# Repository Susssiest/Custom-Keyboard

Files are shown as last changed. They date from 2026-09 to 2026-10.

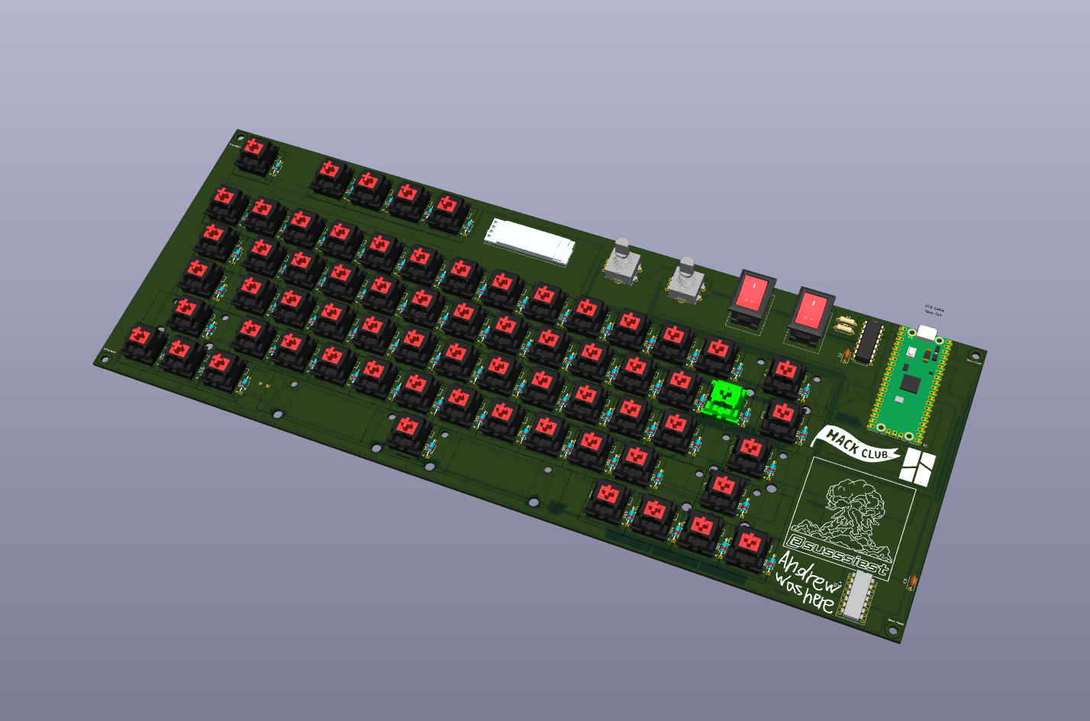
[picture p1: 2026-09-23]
Renders/PCB Render.png

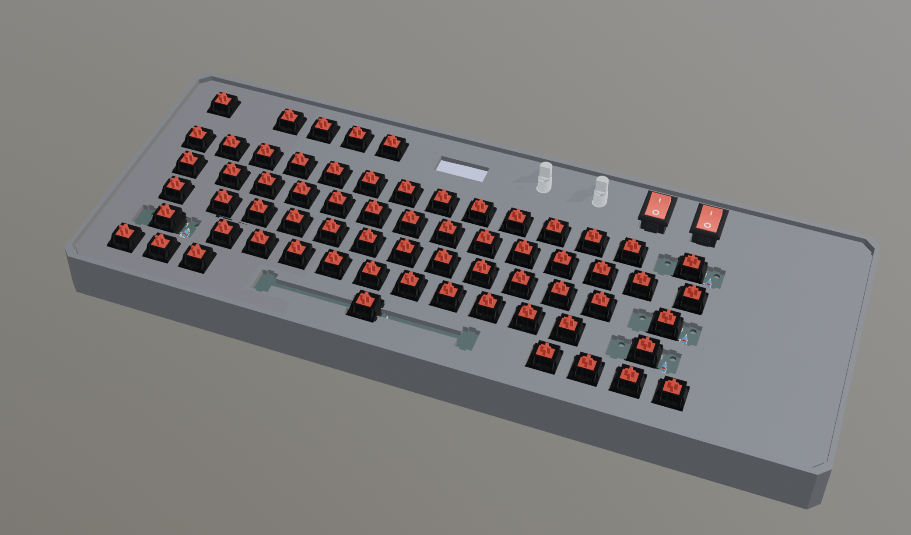
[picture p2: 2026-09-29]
Renders/Full Render.png

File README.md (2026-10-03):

# FORGE CORE

Screenshot 2026-09-23 at 10 50 05 AM
Full Render

## Summary

This is a custom 60% keyboard equipped with per key rgb leds, rotary encoders, rocker switches, and an oled screen. My orginal idea was to just have leds, rotary encoders, and spst switches, but I quickly realized that I needed to add many additional components to get it to work like I intended. The finished keyboard will have many custom features:

- Leds will uniformly glow, and when is a key ismpressed the led under it will flash brighter than all the other leds for a few seconds before fading.
- Rotary encoders will control screen brightness and window switching.
- Spsts will turn leds on and off, and full keyboard on and off.
- I may change function keys to isntead of working like default function keys, open apps, like kicad or fusion.
- Will have Kaihl hot swap sockets.
- OLED will display simple live keylogger.

# Keyboard Overview

## Keyboard Layout

The keyboard's top layer, (R0), is a little different than a normal 60% keyboard. It's main difference is instead of having a full function key layout, the row starts with escape key, and ends with f4, and then has the screen, rotary encoders, and spsts. I will solder on the hot swap sockets to the pcb, and use cherry mx key switches. The matrix will have diodes to right of each key, for each key. 

Screenshot 2026-09-19 at 5 26 41 PM

## Controller and GPIO

I'm planning on using a rp2040 pi pico as the controller, and having an extra gpio extender for the 4 extra pins that don't fit on the pico. The pico will be connected to the full matrix, and link to the led data and rotary encoder a and b signals. The gpio extender will have the two rotary encoder buttons connected to it, snd the two spsts. The PCF8574AP will have a 0.1uf capacitor next to it to protect the 3v3 pin.

Screenshot 2026-09-19 at 5 28 19 PM

## LEDs

LEDs will glow normally and then individually flash when key is pressed, I'm going to limit brightness in firmware as a safeguard. I will have a level shifter for the rgb data to convert the 3.3v data signal to 5v so the leds dont flicker or potentially not recieve commands. I will have a 1000uf capacitor on 5V roght before it reaches the first led. The level shifter will have a 330r resistor before the first led as well. The level shifter will have a 0.1 uf capacitor before 5V to protect the vcc pin.

Screenshot 2026-09-22 at 10 20 40 AM

## Rotary Encoders

I'm planning on one the rotary encoders for controlling volume, and another for controlling windows, I'm planning on configuring it to open the CMD+TAB menu and scroll to select and open windows, and then once the rotary encoder has stopped turnign for say, 1 second, the window will open snd the menu will close.

Screenshot 2026-09-22 at 10 21 06 AM

## SPST Switches

Already mentioned above, one of the spst switches will toggle the LEDs on and off, the other spst will just turn the keyboard on and off.

Screenshot 2026-09-22 at 10 21 21 AM

## OLED

The oled will show a live display of what keys are being pressed, but I may also just put a simple animation on it or logo. There are two 4.7k resistors to protect sda and scl from 3v3.

Screenshot 2026-09-22 at 10 21 35 AM

# Cad Assembly

https://github.com/user-attachments/assets/99ca1ac0-4308-4080-8bde-6a10d6c55312

# Prices

## Keyboard Parts BOM

| Item | Part Number | Description | Quantity | Notes | Price |
|---:|---|---|---:|---|---:|
| 1 | SC0915 | Raspberry Pi Pico | 1 | Microcontroller | $2.27 |
| 2 | MCP23017 | GPIO Extender | 1 | Need one. | $3.23 |
| 3 | KY040 | Rotary Encoder | 2 | — | $2.19 |
| 4 | SSD1306 | 0.91 in Screen | 1 | — | $1.09 |
| 5 | SK6812MINI-E | SK6812 MINI-E Reverse Mount | 66 | Specifically need reverse mount. | $6.04 |
| 6 | CPG151101S11 | Kailh Hot-Swap Sockets | 66 | Type 1, 70 count. | $8.19 |
| 7 | 1N4148 | Diodes | 66 | — | $2.11 |
| 8 | N/A | Ceramic Capacitors | 2 (0.1 µF) | — | $2.48 |
| 9 | N/A | Stabilizers | 6 | Need 2u and 7u. | $6.30 |
| 10 | MX1A | Cherry MX Switches | ~65 | Key switches; brown. | $19.10 |
| 11 | N/A | Shine-Through Keycaps | ~65 | — | $11.18 |
| 12 | KCD1-101 | Rocker Switch | 2 | Have already. | N/A |
| 13 | N/A | Resistors | 3 (330 Ω and 470 kΩ) | Have already. | N/A |
| 14 | Level Shifter | SN74AHCT125N | 1 | Have already. | N/A |
| 15 | N/A | Metal Film Capacitor | 1 (1000 µF) | — | N/A |

**Listed Total:** $64.

## Fabrication Stats

Screenshot 2026-09-23 at 11 26 51 AM

- **Total Price: $26.50**
- **Shipping Estimate: $18.20**

## Download blender files here -> https://drive.google.com/file/d/1HHVWuKGK5Ybn4Eovk-v0dPoQDrp0pe_T/view?usp=sharing

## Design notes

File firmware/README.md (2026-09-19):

# Keyboard (66) QMK Firmware

66-key ANSI 60% + F-row on a Raspberry Pi Pico.

## Files

```
keyboards/hackpad66/
  keyboard.json                 matrix, pins, encoders, RGB layout, LAYOUT_66
  config.h                      I2C0 on GP0/GP1, OLED, RGB brightness cap
  mcuconf.h                     enables the RP2040 I2C0 peripheral
  halconf.h                     enables ChibiOS I2C
  keymaps/default/
    keymap.c                    keymap, Cmd-Tab encoder, OLED, expander
    rules.mk                    pulls in the standalone I2C master driver
```

## Build

```bash
# once
python3 -m pip install --user qmk
qmk setup                       # clones qmk_firmware and installs the ARM toolchain

# copy this board in
cp -r keyboards/hackpad66 ~/qmk_firmware/keyboards/

# compile
qmk compile -kb hackpad66 -km default
```

Flashing: hold BOOTSEL while plugging in the Pico the first time, then drag the
`.uf2` onto the `RPI-RP2` volume. After that, **Fn+Esc** is `QK_BOOT` and puts
the board back into bootloader mode without touching the Pico — which matters,
because RUN is not broken out to a button.

## Pin map

| Function | Pins |
| --- | --- |
| Matrix columns C0–C12 | GP2–GP14 |
| Matrix rows R0–R5 | GP16–GP21 |
| RGB data (66 WS2812) | GP15 → SN74AHCT125N → 330 Ω |
| I2C SDA / SCL | GP0 / GP1 (I2C0) |
| Encoder 1 A / B | GP22 / GP26 |
| Encoder 2 A / B | GP27 / GP28 |

I2C bus: SSD1306 OLED at 0x3C, PCF8574A expander at 0x38 (no collision).

Expander pins: P0 = encoder 1 button, P1 = encoder 2 button,
P2 = left rocker (RGB), P3 = right rocker (screen).

Diode direction is COL2ROW — 1N4148 cathodes on the rows.

## The three relocated switches

To free one GPIO, three switches are wired into matrix row 5 despite sitting
physically elsewhere on the board:

| Switch | Legend | Physical row | Matrix position |
| --- | --- | --- | --- |
| SW7 | `1` | number row | R5, C2 |
| SW21 | `Q` | QWERTY row | R5, C3 |
| SW60 | Left Opt | bottom row | R5, C4 |

`LAYOUT_66` is written in physical reading order, so the keymap hides this.
It is recorded here and at the top of `keymap.c` because nothing in the
schematic or the code hints at it otherwise.

## Behaviour

**Encoder 1 — volume.** `KC_VOLD` / `KC_VOLU`, shaft press is `KC_MUTE`. This
is a host HID consumer-control command, so it adjusts the computer's system
volume and the OS decides which output device that lands on.

**Encoder 2 — app switcher.** Turning presses and holds Cmd, then taps Tab per
detent (Shift+Tab counter-clockwise). Cmd is released 1000 ms after you stop
turning, which commits the switch. Spinning faster than 70 ms per detent sends
2 taps per detent. Shaft press releases Cmd and fires `KC_MCTL` for Mission
Control. Note Cmd+Tab switches *apps*, not individual windows.

Tunables at the top of the Cmd-Tab section: `CMDTAB_COMMIT_MS`,
`CMDTAB_FAST_MS`, `CMDTAB_FAST_STEP`.

**Screen.** Shows currently held keys as `CMD+SHFT+4`. Modifier order is fixed
at Ctrl, Opt, Cmd, Shift, then regular keys. The display is 21 characters wide,
so long combos fall back from `CTRL+OPT+CMD+SHFT` to `C+O+M+S`, and wrap to a
second line only if still too long. Idle shows the board name and active layer.

**Rockers.** Left toggles RGB, right toggles the screen. Both are latching, so
their position is read at boot and applied immediately rather than waited on.

**RGB.** The board runs a moving rainbow across the keys (`cycle_left_right`)
whenever it is powered and the left rocker is on. Fn+F2 cycles to other
animations, Fn+F3/F4 adjust brightness, Fn+F1 toggles the LEDs. On the Fn layer
encoder 1 is brightness and encoder 2 steps through animations.

**RGB current safety.** 66 WS2812s at full white would draw roughly 3.9 A, but
they are fed from Pico VBUS through its polyfuse on a 500 mA port. Brightness
is capped at 110 in both `config.h` and `keyboard.json`. Do not raise it
without external 5 V power, and avoid full-white effects. The LEDs also boot
dark and fade in over ~1 s so they are not drawing current during USB
enumeration while the 1000 µF cap is still charging.

## Things to verify on first flash

These are the parts I could not test without your hardware:

1. **LED chain order.** `keyboard.json` assumes LED *n* in the chain
   corresponds to SW *n*. If your PCB routes the data line in a different
   order, per-key effects will look scrambled — fix the `rgb_matrix.layout`
   array, not the keymap.
2. **Encoder direction.** If an encoder turns the wrong way, swap `pin_a` and
   `pin_b` for it in `keyboard.json`.
3. **Encoder resolution.** Set to 4. If one detent produces two steps, change
   it to 2; if it takes two detents to move once, try 8.
4. **Expander address.** 0x38 assumes the PCF8574**A** variant with A0–A2 tied
   low. The non-A PCF8574 is 0x20 instead.
5. **Rocker polarity.** If a rocker is inverted, flip the `&` tests in
   `exp_task()` and `exp_apply_rockers()`.

## Not compiled

I do not have an ARM toolchain in this sandbox, so this has **not** been
through a compiler. The layout data is machine-verified — 66 keys, 66 LEDs,
66 macro arguments, no duplicate matrix positions — but expect to fix a
warning or two on the first build. The most likely spots are the I2C defines
in `config.h`/`mcuconf.h`, which vary between QMK versions, and the `RM_*`
RGB keycode names, which replaced the older `RGB_*` names in 2025.

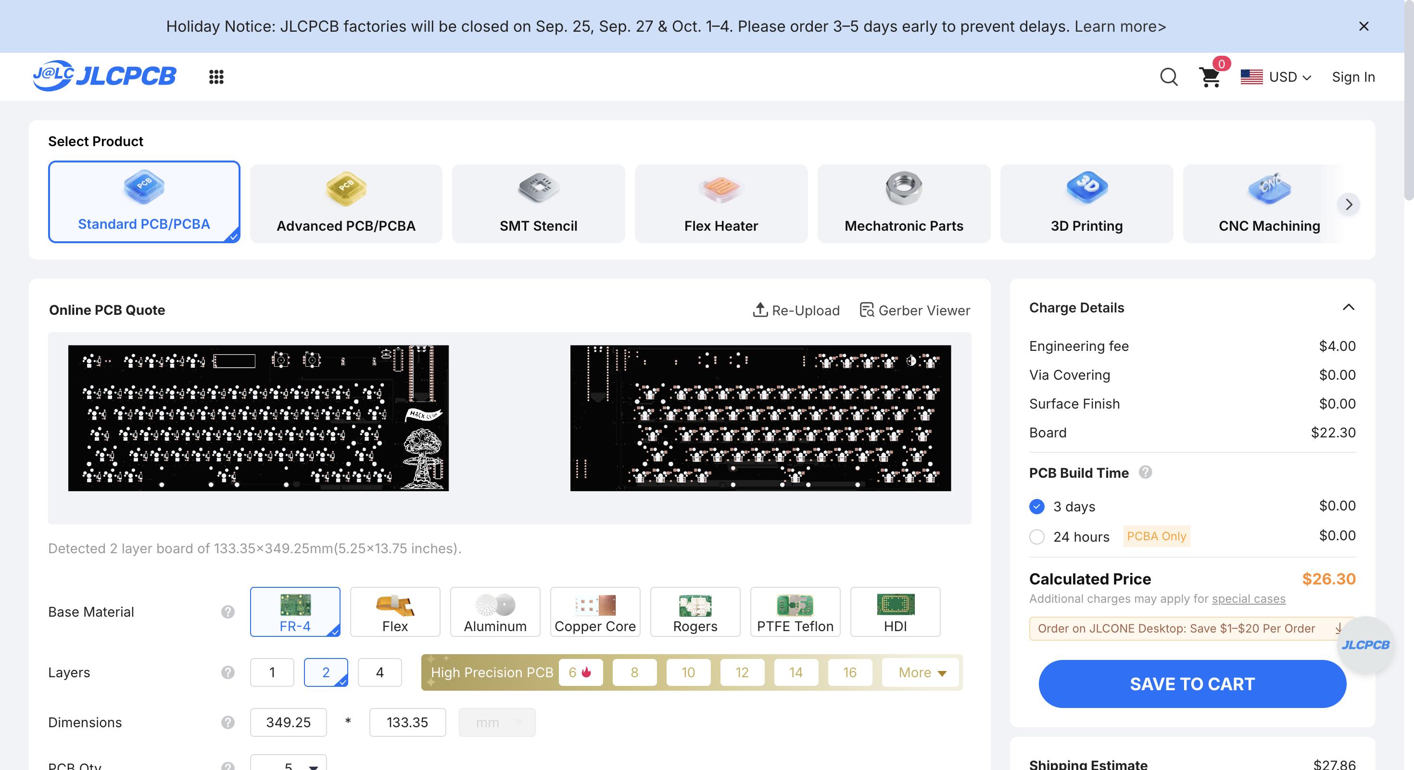
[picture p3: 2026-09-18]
Renders/JLCPCB Overview.png

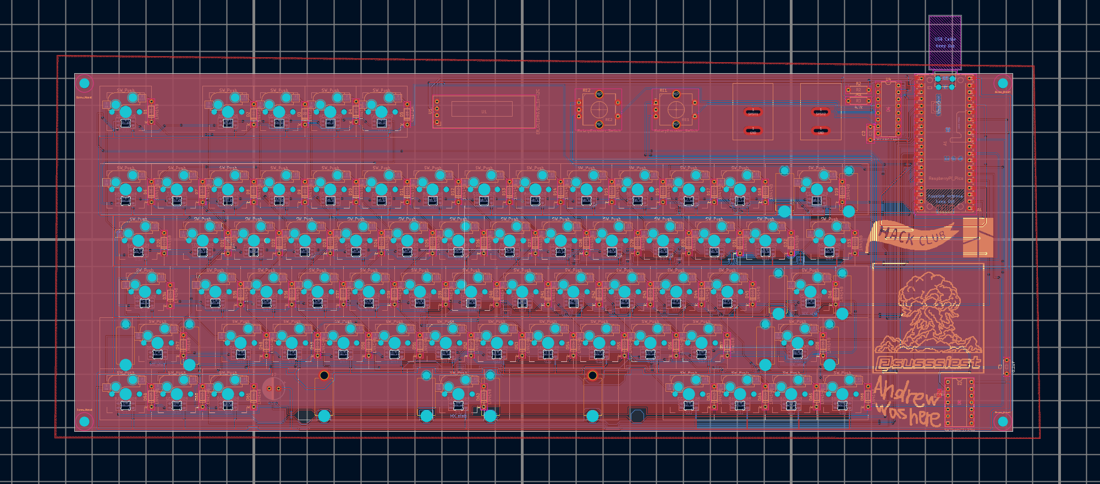
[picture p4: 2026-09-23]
Renders/PCB_Front.png

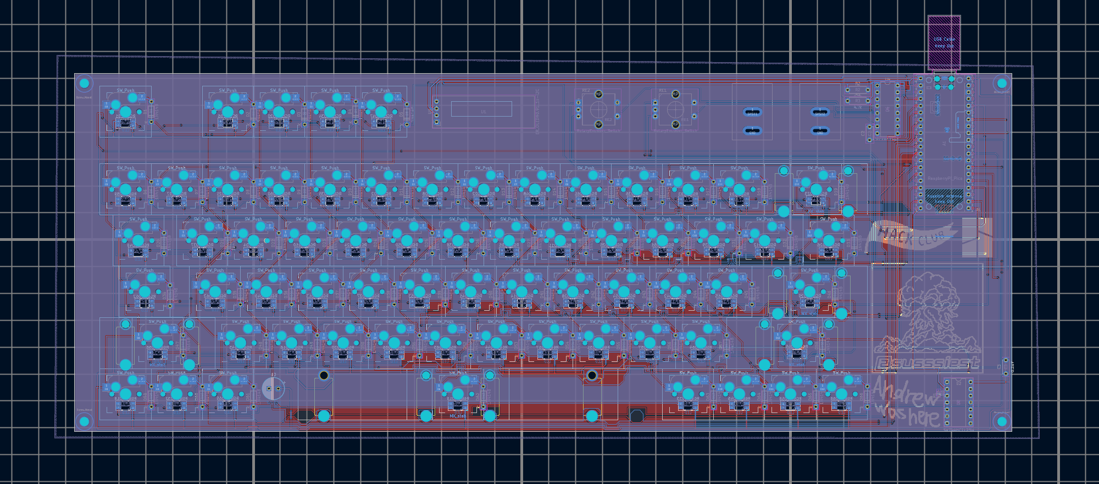
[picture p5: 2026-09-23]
Renders/PCB_Back.png

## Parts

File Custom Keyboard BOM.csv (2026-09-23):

Item | Part Number | Description | Quantity (PART) | Notes | Links | Prices | PCB Manufacturing | Totals | Shipping Estimate
1 | SC0915 | Rasberry Pi Pico | 1 | Micro controller | https://www.aliexpress.us/item/3256805430865417.html?curPageLogUid=Mookv4cZU7gI | $2.27 | $26.50 | Parts -64.19 | ~ $30
2 | MCP23017 | GPIO Extender | 1 | Need one. | https://www.aliexpress.us/item/3256806804890160.html?curPageLogUid=DZaA1o03SMNm | $3.23 |  | PCB - $26.50
3 | KY040 | Rotary Encoder | 2 |  | https://www.aliexpress.us/item/3256807457768762.html?curPageLogUid=t58zUy8mymUw | $2.19 |  | All - $80.69
4 | SSD1306 | 0.91 in Screen | 1 |  | https://www.aliexpress.us/item/2251832650376908.html?gatewayAdapt=glo2usa4itemAdapt | $1.09
5 | SK6812MINI-E | SK6812 MINI-E Reverse Mount | 66 | Specifically need reverse mount. | https://www.aliexpress.us/item/3256805007401420.html?curPageLogUid=upbCtOLX31bt | $6.04
6 | CPG151101S11 | Kaihl Hot Swap Sockets | 66 | Type 1, 70 count. | https://www.aliexpress.us/item/3256811824772840.html?curPageLogUid=uZFKQI2YgP81 | $8.19
7 | 1N4148 | Diodes | 66 |  | https://www.aliexpress.us/item/3256802064723285.html?curPageLogUid=Gxkmaeu7bYkX | $2.11
8 | N/A | Ceramic Capacitors | 2 (0.1uf) |  | https://www.aliexpress.us/item/3256801723894568.html?curPageLogUid=9Tlkmp6Rhsoe | $2.48
9 | N/A | Stabilizers | 6 | Need 2u, 7u. | https://www.aliexpress.us/item/3256806342416791.html?curPageLogUid=XBrMT8oQuSrr | $6.30
10 | MX1A | Cherry MX Switch | ~65 | Key switches. Brown. | https://www.aliexpress.us/item/3256802192387196.html?gatewayAdapt=glo2usa4itemAdapt | $19.10
11 | N/A | Shine through keycaps | ~65 |  | https://www.aliexpress.us/item/3256810117464722.html | $11.18
12 | KCD1-101 | Rocker Switch | 2 | Have already | N/A | N/A
13 | N/A | Resistors | 3 (330r and 470k) | Have already | N/A | N/A
14 | Level Shifter | SN74AHCT125N | 1 | Have already. | N/A | N/A
15 | N/A | Metal Film Capcacitor | 1 (1000 uf) |  | N/A | N/A

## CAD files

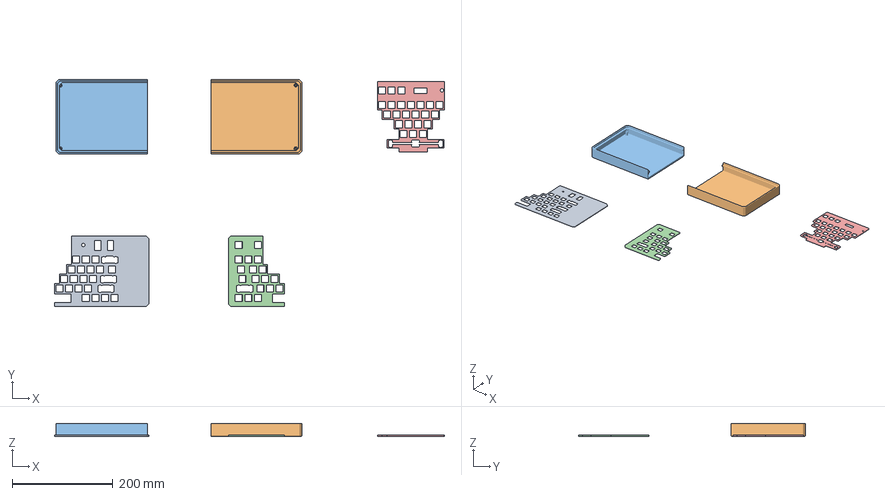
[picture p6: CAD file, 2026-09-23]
CAD/Keyboard_SLICER.3mf
774.9 x 451.2 x 26.6 mm
Plate_Half_1.stl
Case_Half_2.stl
Case_Half_1.stl
Plate_Half_3.stl
Plate_Half_2.stl

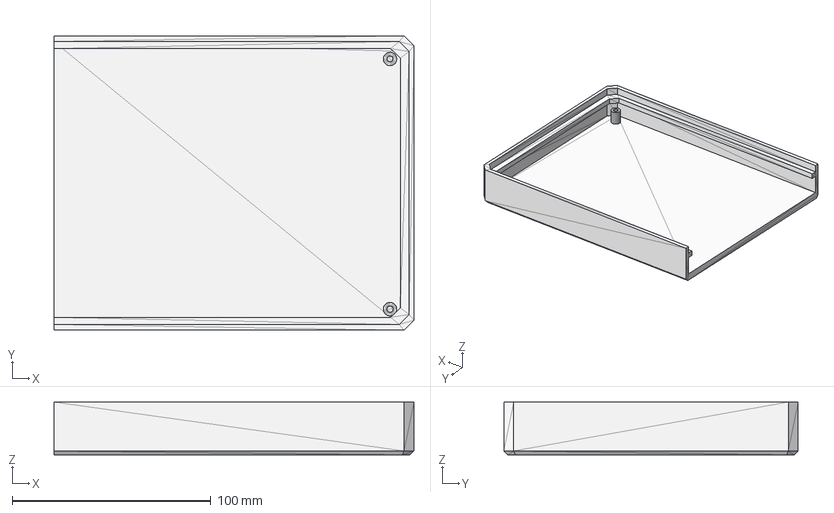
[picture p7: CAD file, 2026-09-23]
CAD/STEPS/Case_Half_2.step
181.0 x 148.0 x 26.6 mm

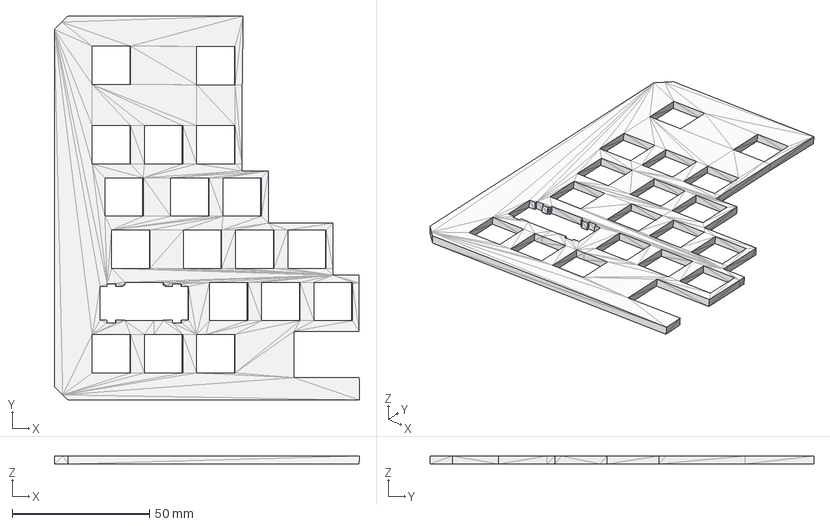
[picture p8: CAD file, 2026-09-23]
CAD/STEPS/Plate_Half_3.step
111.3 x 140.1 x 2.99 mm

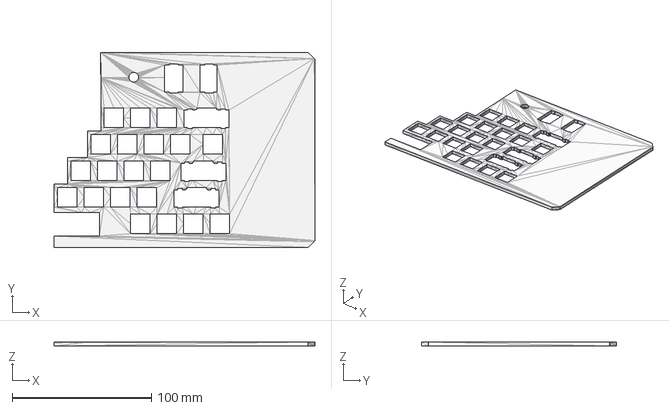
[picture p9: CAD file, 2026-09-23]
CAD/STEPS/Plate_Half_1.step
187.6 x 140.1 x 3.00 mm

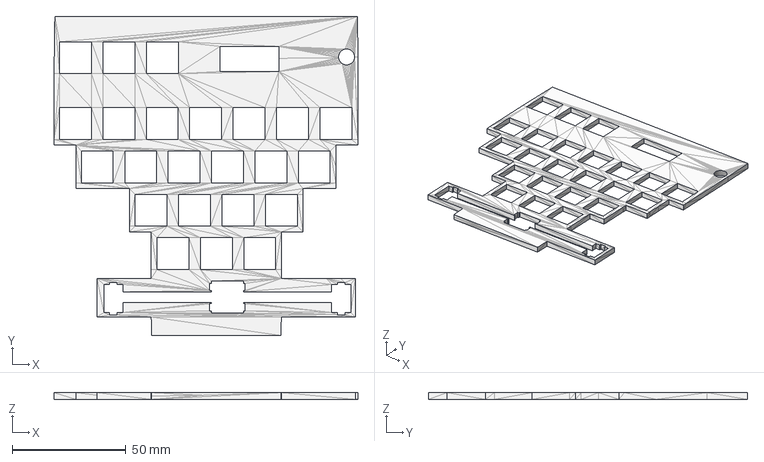
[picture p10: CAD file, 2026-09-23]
CAD/STEPS/Plate_Half_2.step
133.4 x 140.1 x 3.00 mm

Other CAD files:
CAD/STEPS/Case_Half_1.step
CAD/STEPS/PCB Render.step
CAD/STLS/Case_Half_1.stl
CAD/STLS/Case_Half_2.stl
CAD/STLS/Plate_Half_1.stl
CAD/STLS/Plate_Half_2.stl
CAD/STLS/Plate_Half_3.stl

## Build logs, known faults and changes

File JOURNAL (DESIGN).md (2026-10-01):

# Custom-Keyboard Project

## Schematics

I want to make a keyboard with a 60% key layout that has a added row on top for a OLED screen, two rotary encoders, and two toggle switches. I started off doing the basic keyboard matrix and quickly moving on to adding the OLED and rotary encoders. While wiring to the pico, I realized I didn't have enough gpio space for all the electronics. To solve this, I added an mcp23017 to give me more room. After adding it, I realized I also had space for WS2812B leds. I spent maybe 30 minutes adding all the leds, and then moved on to PCB mode.

Screenshot 2026-08-08 at 9 17 37 AM

**Total time spent: 2 hours**

## Orienting Everything in PCB Mode 

I started off with the edge cut for the board outline, and then setting the grid to the distancing between keys, and placing diodes in between. Positioning the rotary encoders, screen, and toggle switches were also pretty easy. The LEDs where my main problem in the PCB editor, after placing a few of them I realized that the LED wouldn't be able to fit on the top side of the board and that they would be crushed by the switches, so I switched it to the bottom layer. After switching layers, the LEDs did give enough room for the keys, but they now faced downwards. I asked a friend and they recommended I use the Sk6812 Mini E Reverse Mount for my keyboard. I found a footprint of the LED and switched all WS2812bBs to the new LEDs, but the LED's footprint was messed up, and I spent around an hour trying to fix it until I just gave up and asked claude. It told me to downlaod one off a github repo, and luckily it worked. I spent another 40 minutes orienting all the LEDs. After finishing, I realized I could add hotswap sockets to make the pcb have holes for the pins in each key instead of having to solder each one on and off. I spent another hour adding the sockets.

PNG image

**Total time spent: 3 hours**

## Routing

I spent around 2 hours routing my keyboard until I realized that I had the diodes connected to each other in a random order, and had to redo their nets in the schematic editor, and then delete all the routed wires. On my second try my routing vastly improved and it took me maybe an hour and thirty minutes to do everything. I started with 5V to the leds and some of the special electronics, and then 3V3 and SDA and SCK. After that I redid the keyboard matrix with my newly organized diodes and connected the other component's data paths like the toggle switches, rotary encoders, and OLED. I spent maybe 30 minutes playing with the ground fill and another hour making DRC stop having a panic attack, and finally was done routing.

Screenshot 2026-08-09 at 4 27 30 PM

**Total time spent: 3 hours**

## Cadding Case

I made my case around the imported 3D model of the pcb. I made the plate and top part split into three pieces to fit on the printer bed, and have a interlocking zigzag connection that will be secured with glue after printing.

Screenshot 2026-08-11 at 8 10 50 PM

**Total time spent: 30 minutes**

## Adding silkscreen

I added an explosion svg lol. For some reason the svg was imported in fully colored in, so it took a little to remove background.

Screenshot 2026-08-09 at 4 57 58 PM

**Total time spent: 10 minutes**

## Added data shifter

I spent around 2 hours adding a data shifter for the LEDs, realized I needed one, luckily I ordered one already for another project, and don't have to add to BOM. Had to rearrange some routing, and also realized that resistor had wrong footprint and fixed that.

Screenshot 2026-09-16 at 5 57 27 PM

**Total time spent: 2 hours**

## Replaced GPIO extender

Replaced the MCP23017 with smaller one that uses scl instead of sck (PCF8574AP) and added HC logo silkscreen. Also added resistors and swapped C11 with C13 on pico to PCF8574AP. Took forever rerouting stuff. This whole process took 2 hours.

PCB

**Total time spent: 2 hours**

## Had wrong level shifter footprint, changed

**Total time spent: 2 hours**

Had footprint for a SN74AH14 instead of a SN74AHCT125N, replaced, and also added a couple resistors for scl  and sda and rearranged capacitor for leds. I also added more silkscreens.

Screenshot 2026-09-19 at 11 01 39 AM

## Combined C0 with other columns.
 
 Combined C0 with other columns so that I don't have one column on the PCF8574AP, and added bambu labs logo silkscreen and my very questionable signature.

Screenshot 2026-09-19 at 10 59 16 AM

**Total time spent: 2 hours**

## Finalizing repo.

Replaced all outdated files, made readme, formatted journal. For some reason my schematic reverted to previous version and I needed to redo capacitors.

Screenshot 2026-09-19 at 5 32 04 PM

**Total time spent: 1 hour**

## Finalized code with qmk.

Talked a bit with perplexity and final code is now finished, I will tweak a little if I run into problems when I have the physical keyboard.

Screenshot 2026-09-19 at 5 39 36 PM

**Total time spent: 1 hour**

## Replaced wrong KCD1 THT footrpint

Made a custom footprint for the kcd1, I'm going to solder the pins onto the pcb, but I had a wrong footprint that made small pin holes, and I had to make my own in footprint editor and implement it into the pcb.

Screenshot 2026-09-21 at 11 41 45 AM

**Total time spent: 30 minutes**

## Added 3d models and fixed footprints

Added all 3D models to board, using step files from grabcad and printables. For some reason some of my footprints were deleted, or switched to other footprints, so I fixed that as well, I also changed the switch's pad orientation because they were a little off centered, and fixed the holes for the hotswap extender thingies because the holes were also a little off centered and they would have had to be sqeezed and potentioally broken to get them to fit. I am pretty confident that I am done with everything.

Screenshot 2026-09-20 at 4 58 46 PM

**Total time spent: 3 hours 30 minutes**

## Updated level shifter footprint.
Replaced old footprint from default pin header to actual 3d model of the SN74AHCT125N.

Screenshot 2026-09-21 at 1 20 00 PM

**Total time spent: 30 minutes**

## Added screw mounting holes.

Found footprint and placed mounting holes in the four corners of the pcb. Needed to do a little rerouting, but did it pretty easily.

Screenshot 2026-09-22 at 11 10 30 AM

**Total time spent: 20 minutes**

## Updated PCB mounting and plate mounting system, and made a assembly animation.

Added a new screw hole mount to the actual cad for the pcb, and added a extrusion in the case that holds the plate up. Also used blender animation tools to make a fire assembly animation.

Screenshot 2026-09-22 at 6 13 17 PM

**Total time spent: 1 hour**

## Changed spacebar key to 6u because i cant find any sets with 7u lol.

Changed spacebar footprint and updated routing along it. Also updated BOM.

Screenshot 2026-09-22 at 7 05 12 PM

**Total time spent: 30 minutes**

## Fixed silkscreen for hotswaps.
Silkscreen was completely on f.cu, moved hotswap parts to back side. Looking good, I'm pretty confident that I am done.

Screenshot 2026-09-23 at 10 27 00 AM

**Total time spent: 30 minutes**

## Added USB C Hole.

Made a usbc cutout and applied boolean, and then uploaded to stl folder and converted to step. Now I'm done lol.

Screenshot 2026-09-24 at 11 37 58 AM

## Final documentation edits.

Updated BOM, gerber/drill files, added renders to readme, updated journal, and generally polished everything up.

Screenshot 2026-09-22 at 7 29 22 PM

**Total time spent: 30 minutes**

## Sorting all the random pcb components into collections and then redid assemby.

The keybaord was basically returned because my assembly sucks. So I fixed it. But, it was lazy for a specific reason. If I export the cad as a glb, it puts everything in a node, and it scales it to a thousandth of the size. The nodes for some reason are randomly linked to other objects for some reason, so say I move a switch on the right of the keyboard, it will also move a diode on the complete opposite side in the same way. I spent 30 literal minutes being confused and moving stuff around. Then I gave up and deleted everything, and re addded the pcb files. I un-noded everything, but then I realized that it multiplied the amount of objects by like 5. For some reason, each led took up 5 different objects that are in completely differant areas on the parts list, one object for the main led, and then 4 more for each singlar pin extruding it. The keys also took up two objects each, one for casing, one for + thing on top, and the hotswaps took up 3 objects, one for main hotswap part, two for pins extruding from it. So I had to painstakingly sort over 600 objects into 12 differant folders. This took me around 2 hours, 40 minutes. I then chose to skip renaming every part, because for some reason random components had names like this. **=>[0:1:1:30].057** I dont knwo why the hell they had names like that, ask kicad.  I also had to redo the colors on some imported parts because a few specific part had just see through materials for some stupid fucking reason, so I just went around copying and pasting hex codes for 30 minutes. I finally finished sorting everything, and animated it. The animation is pretty simple, it took 30 minutes to make. I was so tired that instead of setting up a camera and lighting, I just took a screen recording in material preview mode. It also took me around 20 minutes to upload and change everything in github.

Screenshot 2026-09-28 at 5 53 26 PM

**Total time spent: 4 hours**

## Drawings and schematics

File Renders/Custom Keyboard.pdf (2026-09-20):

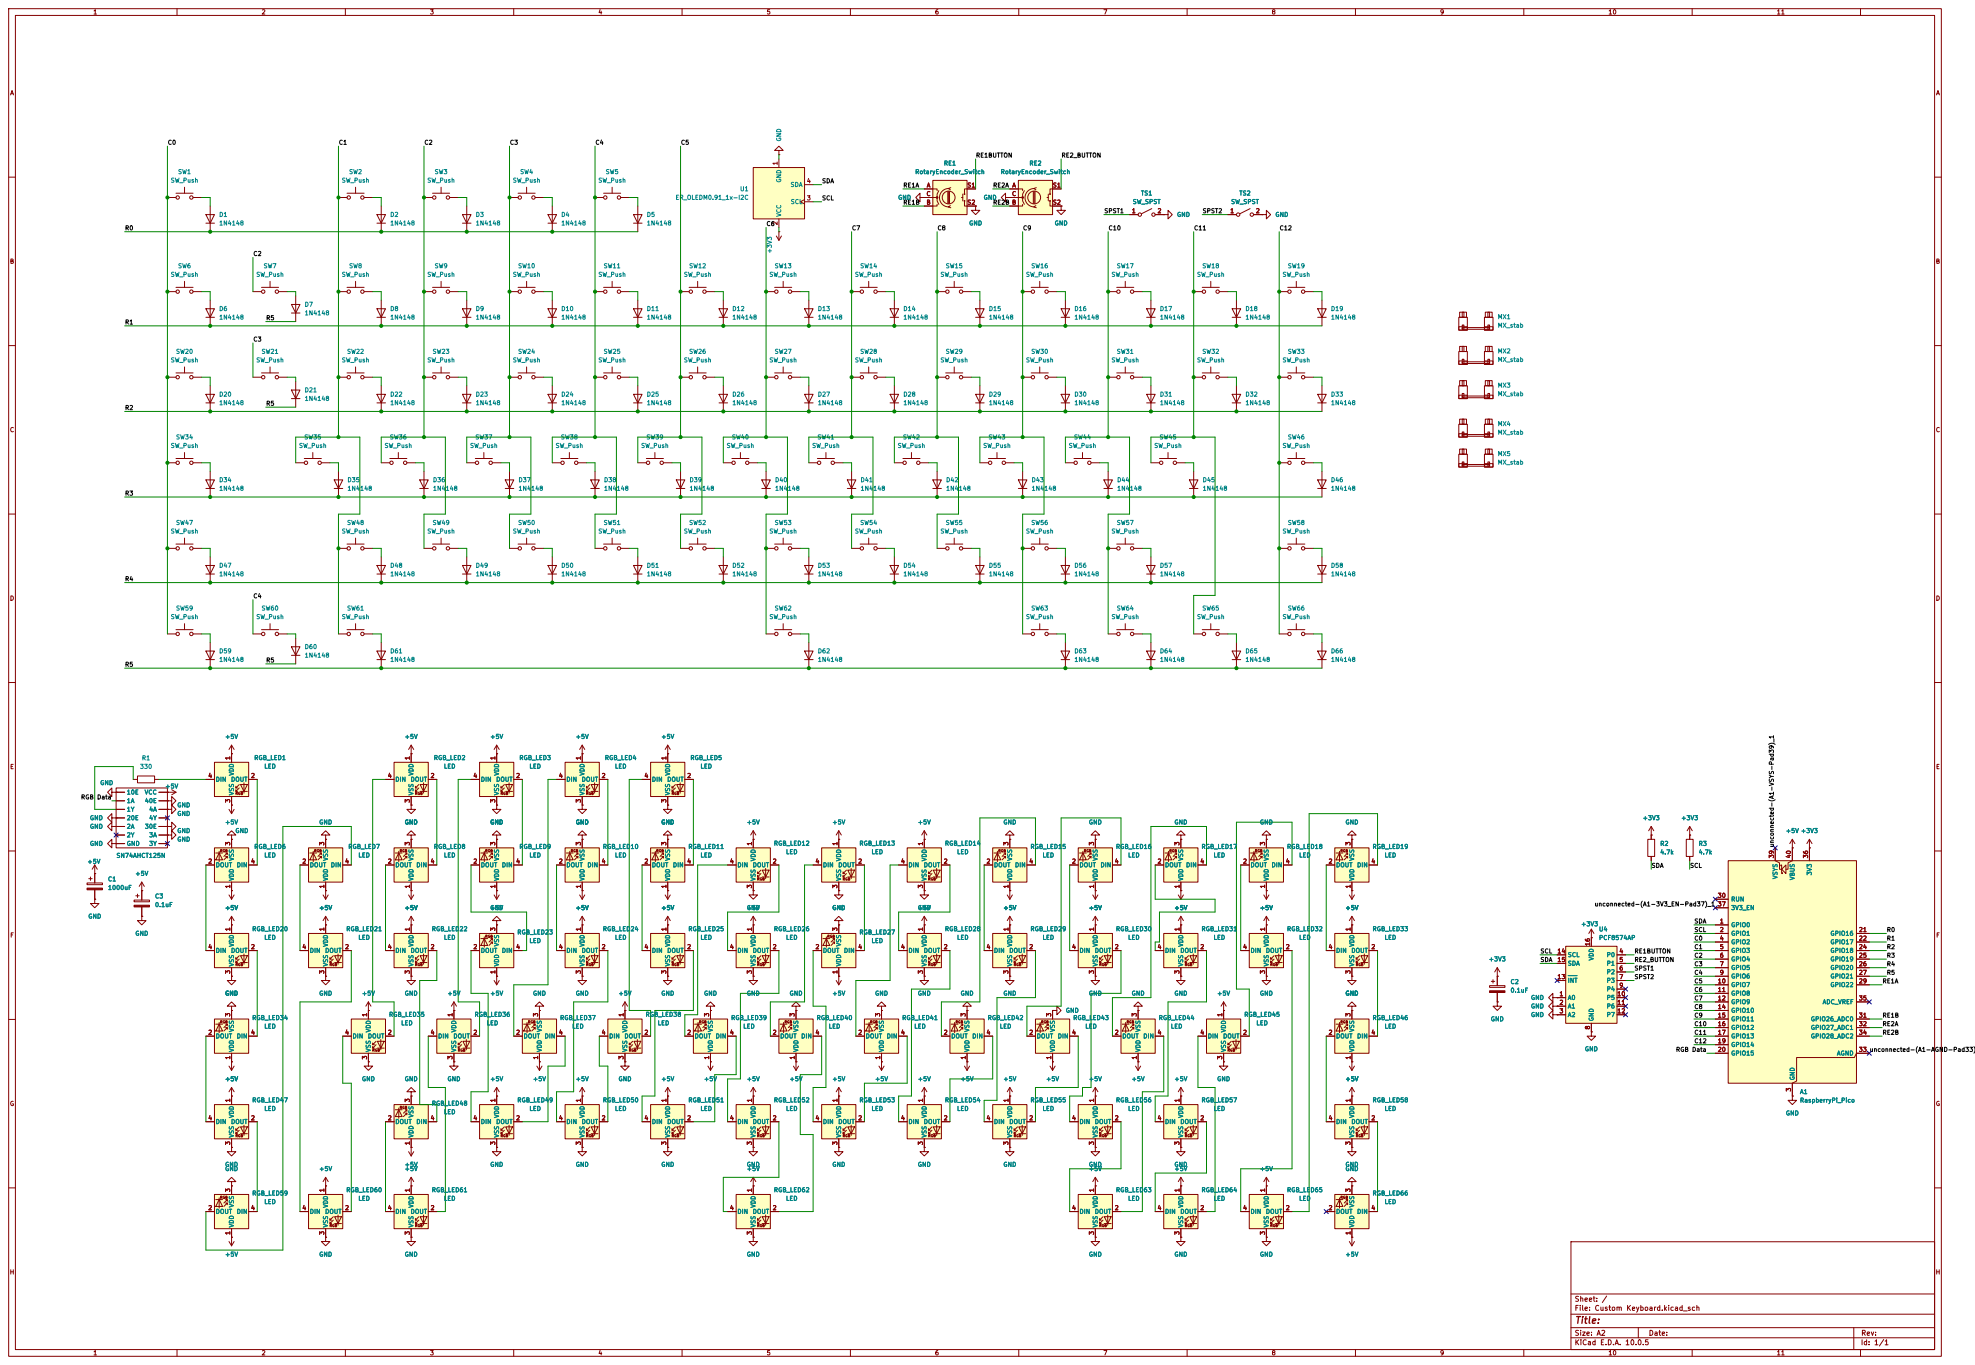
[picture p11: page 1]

3 DIN 4 GND GND +5V GND GND +5V RGB_LED11

Size: A2 | Rev:
KiCad E.D.A. 10.0.5 | Id: 1/1

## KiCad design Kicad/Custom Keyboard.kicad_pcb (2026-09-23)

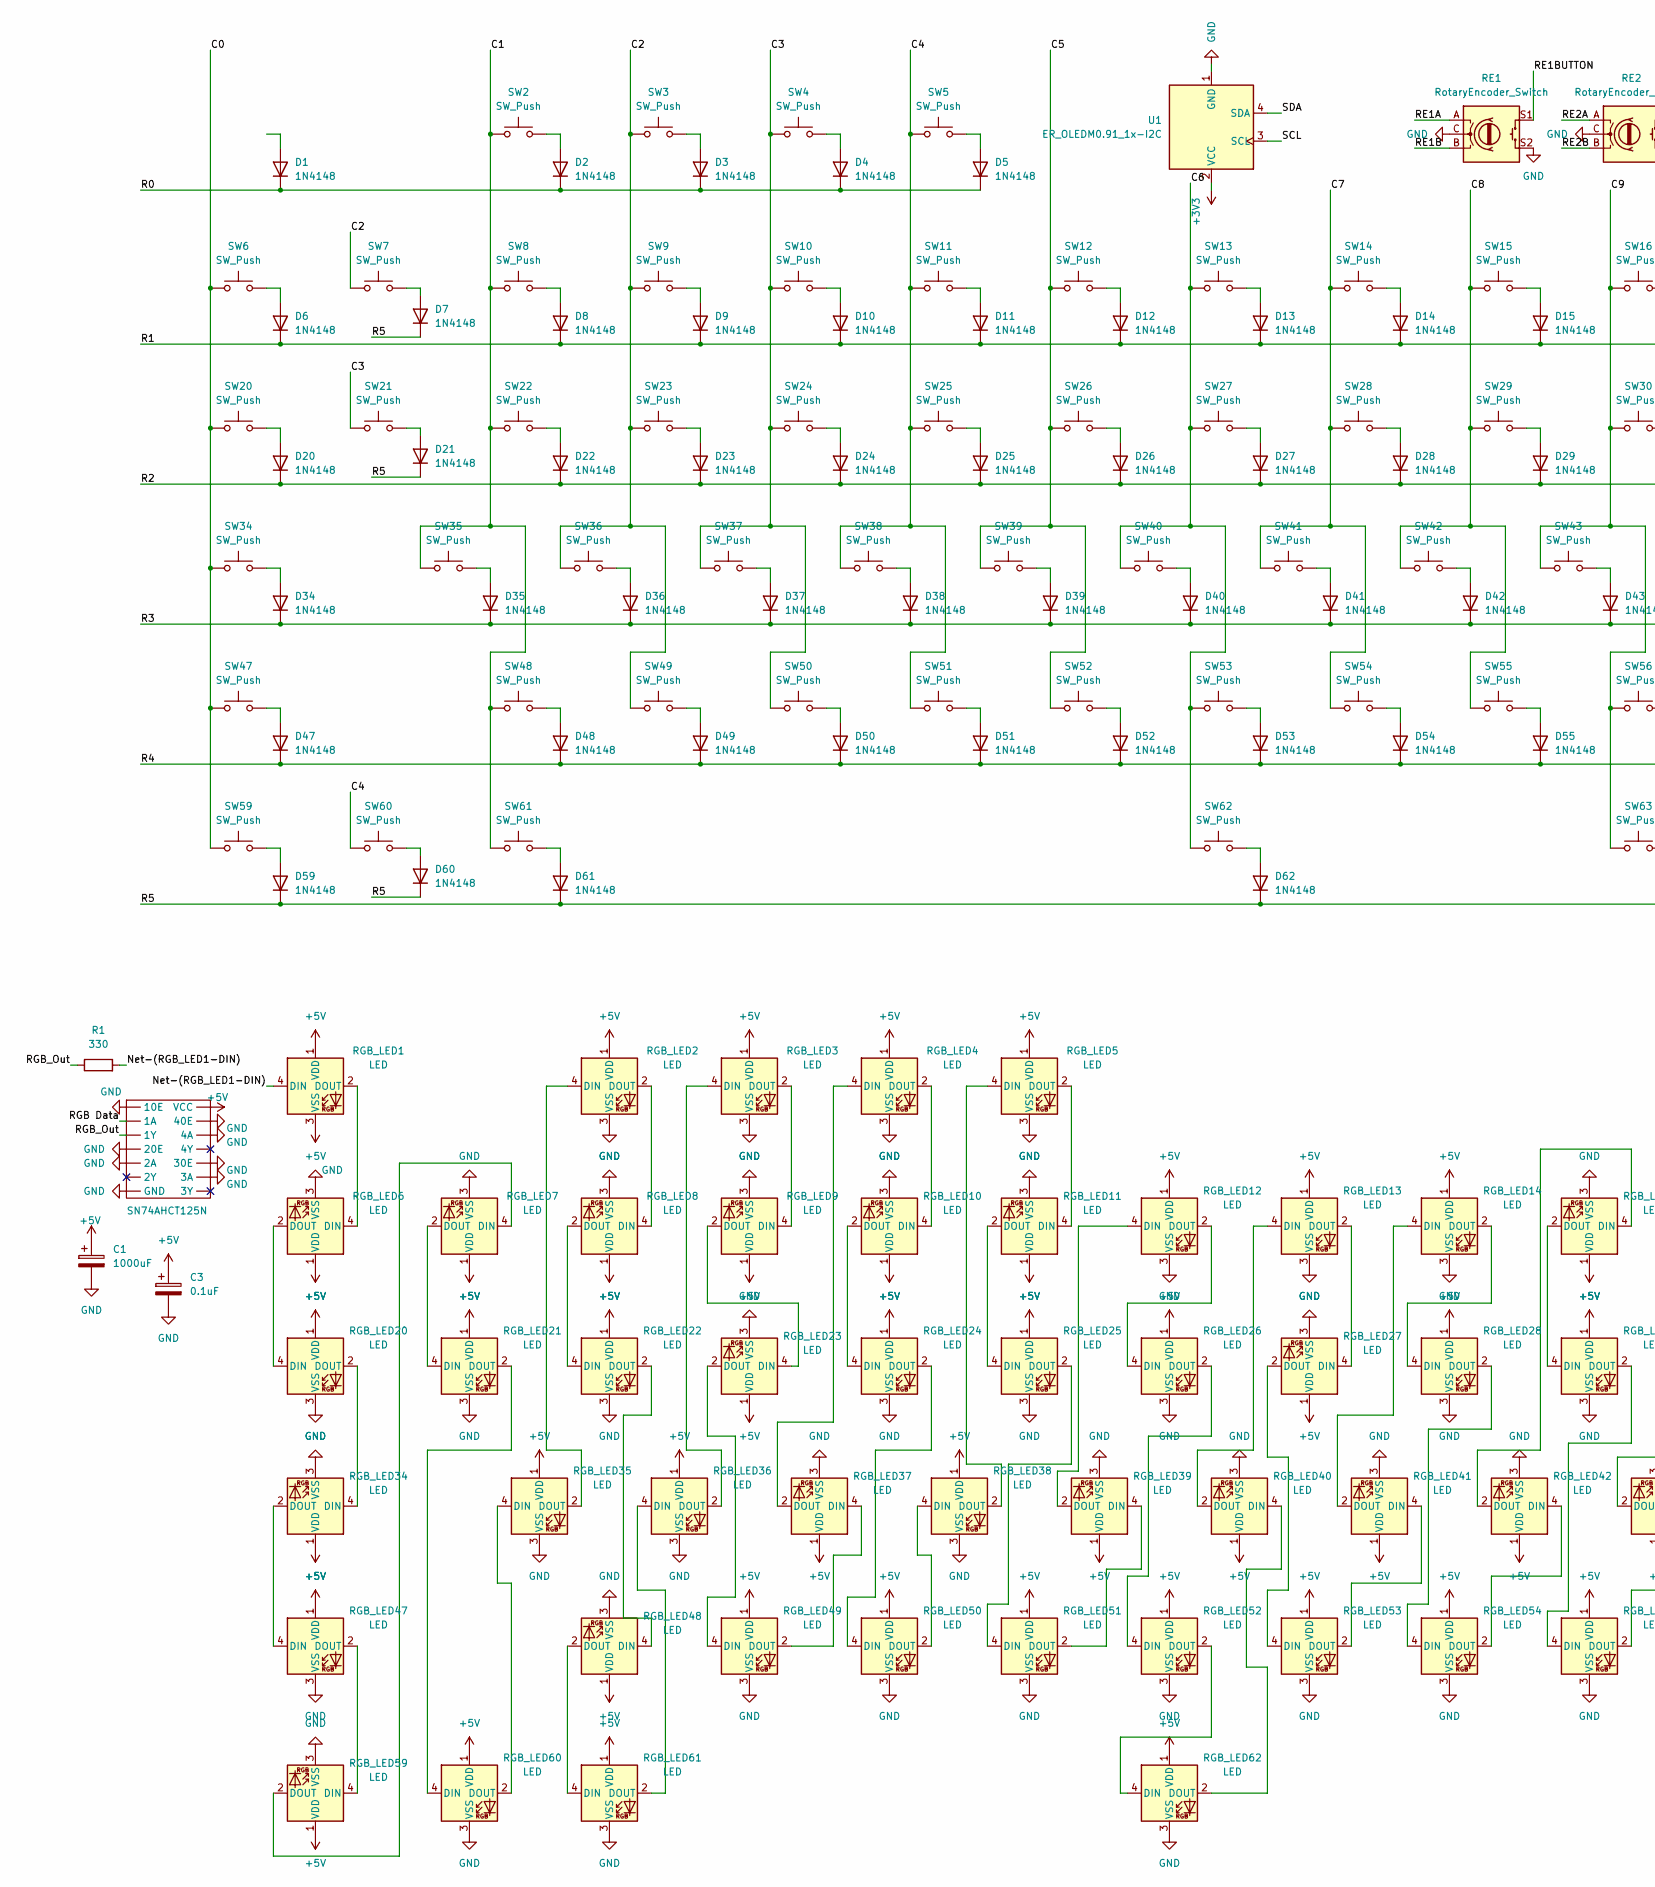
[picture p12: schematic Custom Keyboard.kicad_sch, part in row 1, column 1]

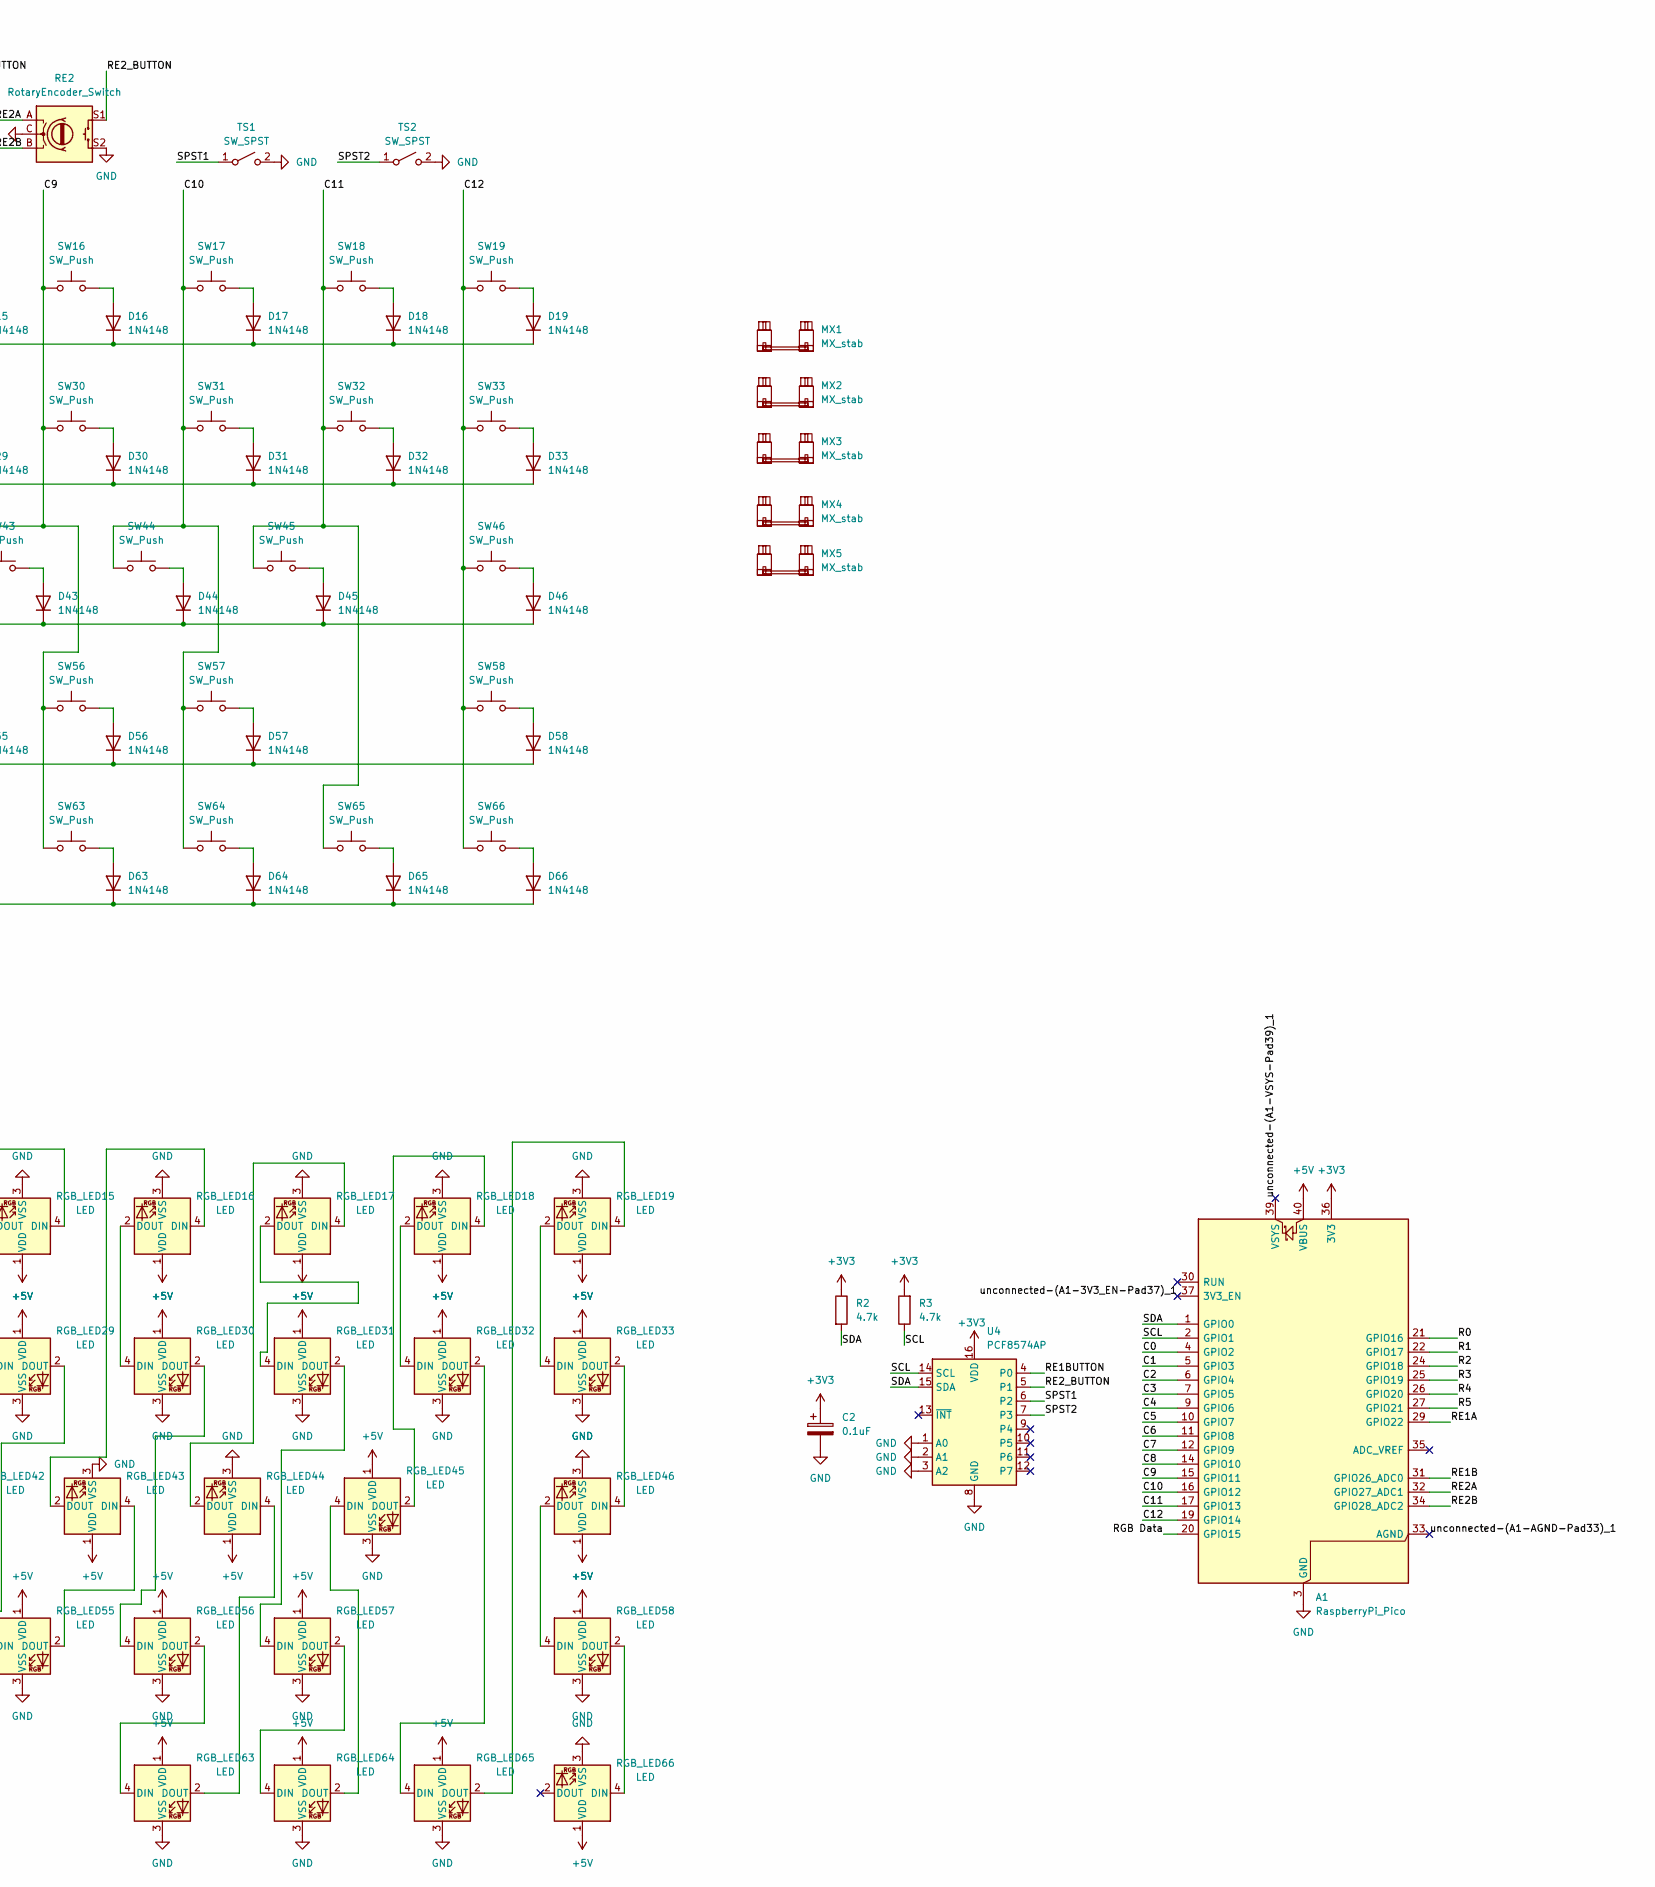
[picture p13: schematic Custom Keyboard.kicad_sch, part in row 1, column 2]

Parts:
A1: RaspberryPi_Pico; RaspberryPi_Pico_Common_Unspecified
C1: 1000uF; CP_Radial_D8.0mm_P3.50mm
C2, C3: 0.1uF; C_Disc_D5.0mm_W2.5mm_P5.00mm
D1, D2, D3, D4, D5, D6, D7, D8, D9, D10, D11, D12, D13, D14, D15, D16, D17, D18, D19, D20, D21, D22, D23, D24, D25, D26, D27, D28, D29, D30, D31, D32, D33, D34, D35, D36, D37, D38, D39, D40, D41, D42, D43, D44, D45, D46, D47, D48, D49, D50, D51, D52, D53, D54, D55, D56, D57, D58, D59, D60, D61, D62, D63, D64, D65, D66: 1N4148; D_DO-35_SOD27_P7.62mm_Horizontal
MX1: MX_stab; STAB_MX_P_7u
MX2, MX3: MX_stab; STAB_MX_2.25u
MX4: MX_stab; STAB_MX_2.75u
MX5: MX_stab; STAB_MX_2u
R1: 330; R_0603_1608Metric
R2, R3: 4.7k; R_Axial_DIN0207_L6.3mm_D2.5mm_P7.62mm_Horizontal
RE1, RE2: RotaryEncoder_Switch; RotaryEncoder_Alps_EC11E-Switch_Vertical_H20mm_CircularMoun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
RGB_LED1, RGB_LED2, RGB_LED3, RGB_LED4, RGB_LED5, RGB_LED6, RGB_LED7, RGB_LED8, RGB_LED9, RGB_LED10, RGB_LED11, RGB_LED12, RGB_LED13, RGB_LED14, RGB_LED15, RGB_LED16, RGB_LED17, RGB_LED18, RGB_LED19, RGB_LED20, RGB_LED21, RGB_LED22, RGB_LED23, RGB_LED24, RGB_LED25, RGB_LED26, RGB_LED27, RGB_LED28, RGB_LED29, RGB_LED30, RGB_LED31, RGB_LED32, RGB_LED33, RGB_LED34, RGB_LED35, RGB_LED36, RGB_LED37, RGB_LED38, RGB_LED39, RGB_LED40, RGB_LED41, RGB_LED42, RGB_LED43, RGB_LED44, RGB_LED45, RGB_LED46, RGB_LED47, RGB_LED48, RGB_LED49, RGB_LED50, RGB_LED51, RGB_LED52, RGB_LED53, RGB_LED54, RGB_LED55, RGB_LED56, RGB_LED57, RGB_LED58, RGB_LED59, RGB_LED60, RGB_LED61, RGB_LED62, RGB_LED63, RGB_LED64, RGB_LED65, RGB_LED66: LED; LED_SK6812MINI-E_3.2x2.8mm_P1.5mm_ReverseMount
SW2, SW3, SW4, SW5, SW6, SW7, SW8, SW9, SW10, SW11, SW12, SW13, SW14, SW15, SW16, SW17, SW18, SW19, SW20, SW21, SW22, SW23, SW24, SW25, SW26, SW27, SW28, SW29, SW30, SW31, SW32, SW33, SW34, SW35, SW36, SW37, SW38, SW39, SW40, SW41, SW42, SW43, SW44, SW45, SW46, SW47, SW48, SW49, SW50, SW51, SW52, SW53, SW54, SW55, SW56, SW57, SW58, SW59, SW60, SW61, SW62, SW63, SW64, SW65, SW66: SW_Push; MX_Hotswap
TS1, TS2: SW_SPST; KCD1_THT
U1: ER_OLEDM0.91_1x-I2C
U2: SN74AHCT125N
U4: PCF8574AP; DIP-16_W7.62mm

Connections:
+3V3: A1.36 (3V3), C2.1, R2.1, R3.2, U1.2 (VCC), U4.16 (VDD)
+5V: A1.40 (VBUS), C1.1, C3.1, RGB_LED1.1 (VDD), RGB_LED1.3 (VSS), RGB_LED2.1 (VDD), RGB_LED3.1 (VDD), RGB_LED4.1 (VDD), RGB_LED5.1 (VDD), RGB_LED6.1 (VDD), RGB_LED7.1 (VDD), RGB_LED8.1 (VDD), RGB_LED9.1 (VDD), RGB_LED10.1 (VDD), RGB_LED11.1 (VDD), RGB_LED12.1 (VDD), RGB_LED13.1 (VDD), RGB_LED14.1 (VDD), RGB_LED15.1 (VDD), RGB_LED16.1 (VDD), RGB_LED17.1 (VDD), RGB_LED18.1 (VDD), RGB_LED19.1 (VDD), RGB_LED20.1 (VDD), RGB_LED21.1 (VDD), RGB_LED22.1 (VDD), RGB_LED23.1 (VDD), RGB_LED24.1 (VDD), RGB_LED25.1 (VDD), RGB_LED26.1 (VDD), RGB_LED27.1 (VDD), RGB_LED28.1 (VDD), RGB_LED29.1 (VDD), RGB_LED30.1 (VDD), RGB_LED31.1 (VDD), RGB_LED32.1 (VDD), RGB_LED33.1 (VDD), RGB_LED34.1 (VDD), RGB_LED35.1 (VDD), RGB_LED36.1 (VDD), RGB_LED37.1 (VDD), RGB_LED38.1 (VDD), RGB_LED39.1 (VDD), RGB_LED40.1 (VDD), RGB_LED41.1 (VDD), RGB_LED42.1 (VDD), RGB_LED43.1 (VDD), RGB_LED44.1 (VDD), RGB_LED45.1 (VDD), RGB_LED46.1 (VDD), RGB_LED47.1 (VDD), RGB_LED48.1 (VDD), RGB_LED49.1 (VDD), RGB_LED50.1 (VDD), RGB_LED51.1 (VDD), RGB_LED52.1 (VDD), RGB_LED53.1 (VDD), RGB_LED54.1 (VDD), RGB_LED55.1 (VDD), RGB_LED56.1 (VDD), RGB_LED57.1 (VDD), RGB_LED58.1 (VDD), RGB_LED59.1 (VDD), RGB_LED60.1 (VDD), RGB_LED61.1 (VDD), RGB_LED62.1 (VDD), RGB_LED63.1 (VDD), RGB_LED64.1 (VDD), RGB_LED65.1 (VDD), RGB_LED66.1 (VDD), U2., U2.VCC
/C0: A1.4 (GPIO2), SW6.1, SW20.1, SW34.1, SW47.1, SW59.1; also elsewhere on the board
/C1: A1.5 (GPIO3), SW2.1, SW8.1, SW22.1, SW35.1, SW48.1, SW61.1
/C2: A1.6 (GPIO4), SW3.1, SW7.1, SW9.1, SW23.1, SW36.1, SW49.1
/C3: A1.7 (GPIO5), SW4.1, SW10.1, SW21.1, SW24.1, SW37.1, SW50.1
/C4: A1.9 (GPIO6), SW5.1, SW11.1, SW25.1, SW38.1, SW51.1, SW60.1
/C5: A1.10 (GPIO7), SW12.1, SW26.1, SW39.1, SW52.1
/C6: A1.11 (GPIO8), SW13.1, SW27.1, SW40.1, SW53.1, SW62.1
/C7: A1.12 (GPIO9), SW14.1, SW28.1, SW41.1, SW54.1
/C8: A1.14 (GPIO10), SW15.1, SW29.1, SW42.1, SW55.1
/C9: A1.15 (GPIO11), SW16.1, SW30.1, SW43.1, SW56.1, SW63.1
/C10: A1.16 (GPIO12), SW17.1, SW31.1, SW44.1, SW57.1, SW64.1
/C11: A1.17 (GPIO13), SW18.1, SW32.1, SW45.1, SW65.1
/C12: A1.19 (GPIO14), SW19.1, SW33.1, SW46.1, SW58.1, SW66.1
/Net-(RGB_LED1-DIN): R1.2, RGB_LED1.4 (DIN)
/R0: A1.21 (GPIO16), D1.1 (K), D2.1 (K), D3.1 (K), D4.1 (K), D5.1 (K)
/R1: A1.22 (GPIO17), D6.1 (K), D8.1 (K), D9.1 (K), D10.1 (K), D11.1 (K), D12.1 (K), D13.1 (K), D14.1 (K), D15.1 (K), D16.1 (K), D17.1 (K), D18.1 (K), D19.1 (K)
/R2: A1.24 (GPIO18), D20.1 (K), D22.1 (K), D23.1 (K), D24.1 (K), D25.1 (K), D26.1 (K), D27.1 (K), D28.1 (K), D29.1 (K), D30.1 (K), D31.1 (K), D32.1 (K), D33.1 (K)
/R3: A1.25 (GPIO19), D34.1 (K), D35.1 (K), D36.1 (K), D37.1 (K), D38.1 (K), D39.1 (K), D40.1 (K), D41.1 (K), D42.1 (K), D43.1 (K), D44.1 (K), D45.1 (K), D46.1 (K)
/R4: A1.26 (GPIO20), D47.1 (K), D48.1 (K), D49.1 (K), D50.1 (K), D51.1 (K), D52.1 (K), D53.1 (K), D54.1 (K), D55.1 (K), D56.1 (K), D57.1 (K), D58.1 (K)
/R5: A1.27 (GPIO21), D7.1 (K), D21.1 (K), D59.1 (K), D60.1 (K), D61.1 (K), D62.1 (K), D63.1 (K), D64.1 (K), D65.1 (K), D66.1 (K)
/RE1A: A1.29 (GPIO22), RE1.A
/RE1B: A1.31 (GPIO26_ADC0), RE1.B
/RE1BUTTON: RE1.S1, U4.4 (P0)
/RE2A: A1.32 (GPIO27_ADC1), RE2.A
/RE2B: A1.34 (GPIO28_ADC2), RE2.B
/RE2_BUTTON: RE2.S1, U4.5 (P1)
/RGB Data: A1.20 (GPIO15), U2., U2.1A
/SCL: A1.2 (GPIO1), R3.1, U1.3 (SCL), U4.14 (SCL)
/SDA: A1.1 (GPIO0), R2.2, U1.4 (SDA), U4.15 (SDA)
/unconnected-(A1-3V3_EN-Pad37)_1: A1.37 (3V3_EN)
/unconnected-(A1-3V3_EN-Pad37)_1_1: A1.37 (3V3_EN)
/unconnected-(A1-AGND-Pad33)_1: A1.33 (AGND)
/unconnected-(A1-AGND-Pad33)_1_1: A1.33 (AGND)
/unconnected-(A1-VSYS-Pad39)_1: A1.39 (VSYS)
/unconnected-(A1-VSYS-Pad39)_1_1: A1.39 (VSYS)
GND: A1.3 (GND), A1.8 (GND), A1.13 (GND), A1.18 (GND), A1.23 (GND), A1.28 (GND), A1.38 (GND), C1.2, C2.2, C3.2, RE1.C, RE1.S2, RE2.C, RE2.S2, RGB_LED2.3 (VSS), RGB_LED3.3 (VSS), RGB_LED4.3 (VSS), RGB_LED5.3 (VSS), RGB_LED6.3 (VSS), RGB_LED7.3 (VSS), RGB_LED8.3 (VSS), RGB_LED9.3 (VSS), RGB_LED10.3 (VSS), RGB_LED11.3 (VSS), RGB_LED12.3 (VSS), RGB_LED13.3 (VSS), RGB_LED14.3 (VSS), RGB_LED15.3 (VSS), RGB_LED16.3 (VSS), RGB_LED17.3 (VSS), RGB_LED18.3 (VSS), RGB_LED19.3 (VSS), RGB_LED20.3 (VSS), RGB_LED21.3 (VSS), RGB_LED22.3 (VSS), RGB_LED23.3 (VSS), RGB_LED24.3 (VSS), RGB_LED25.3 (VSS), RGB_LED26.3 (VSS), RGB_LED27.3 (VSS), RGB_LED28.3 (VSS), RGB_LED29.3 (VSS), RGB_LED30.3 (VSS), RGB_LED31.3 (VSS), RGB_LED32.3 (VSS), RGB_LED33.3 (VSS), RGB_LED34.3 (VSS), RGB_LED35.3 (VSS), RGB_LED36.3 (VSS), RGB_LED37.3 (VSS), RGB_LED38.3 (VSS), RGB_LED39.3 (VSS), RGB_LED40.3 (VSS), RGB_LED41.3 (VSS), RGB_LED42.3 (VSS), RGB_LED43.3 (VSS), RGB_LED44.3 (VSS), RGB_LED45.3 (VSS), RGB_LED46.3 (VSS), RGB_LED47.3 (VSS), RGB_LED48.3 (VSS), RGB_LED49.3 (VSS), RGB_LED50.3 (VSS), RGB_LED51.3 (VSS), RGB_LED52.3 (VSS), RGB_LED53.3 (VSS), RGB_LED54.3 (VSS), RGB_LED55.3 (VSS), RGB_LED56.3 (VSS), RGB_LED57.3 (VSS), RGB_LED58.3 (VSS), RGB_LED59.3 (VSS), RGB_LED60.3 (VSS), RGB_LED61.3 (VSS), RGB_LED62.3 (VSS), RGB_LED63.3 (VSS), RGB_LED64.3 (VSS), RGB_LED65.3 (VSS), RGB_LED66.3 (VSS), TS2.1 (A), TS2.2 (B), U1.1 (GND), U2., U2.1OE, U2.2A, U2.2OE, U2.3A, U2.3OE, U2.4A, U2.4OE, U2.GND, U4.1 (A0), U4.2 (A1), U4.3 (A2), U4.8 (GND); also elsewhere on the board
unnamed 38: D1.2 (A); also elsewhere on the board
unnamed: D2.2 (A), SW2.2
unnamed: D3.2 (A), SW3.2
unnamed: D4.2 (A), SW4.2
unnamed: D5.2 (A), SW5.2
unnamed: D6.2 (A), SW6.2
unnamed: D7.2 (A), SW7.2
unnamed: D8.2 (A), SW8.2
unnamed: D9.2 (A), SW9.2
unnamed: D10.2 (A), SW10.2
unnamed: D11.2 (A), SW11.2
unnamed: D12.2 (A), SW12.2
unnamed: D13.2 (A), SW13.2
unnamed: D14.2 (A), SW14.2
unnamed: D15.2 (A), SW15.2
unnamed: D16.2 (A), SW16.2
unnamed: D17.2 (A), SW17.2
unnamed: D18.2 (A), SW18.2
unnamed: D19.2 (A), SW19.2
unnamed: D20.2 (A), SW20.2
unnamed: D21.2 (A), SW21.2
unnamed: D22.2 (A), SW22.2
unnamed: D23.2 (A), SW23.2
unnamed: D24.2 (A), SW24.2
unnamed: D25.2 (A), SW25.2
unnamed: D26.2 (A), SW26.2
unnamed: D27.2 (A), SW27.2
unnamed: D28.2 (A), SW28.2
unnamed: D29.2 (A), SW29.2
unnamed: D30.2 (A), SW30.2
unnamed: D31.2 (A), SW31.2
unnamed: D32.2 (A), SW32.2
unnamed: D33.2 (A), SW33.2
unnamed: D34.2 (A), SW34.2
unnamed: D35.2 (A), SW35.2
unnamed: D36.2 (A), SW36.2
unnamed: D37.2 (A), SW37.2
unnamed: D38.2 (A), SW38.2
unnamed: D39.2 (A), SW39.2
unnamed: D40.2 (A), SW40.2
unnamed: D41.2 (A), SW41.2
unnamed: D42.2 (A), SW42.2
unnamed: D43.2 (A), SW43.2
unnamed: D44.2 (A), SW44.2
unnamed: D45.2 (A), SW45.2
unnamed: D46.2 (A), SW46.2
unnamed: D47.2 (A), SW47.2
unnamed: D48.2 (A), SW48.2
unnamed: D49.2 (A), SW49.2
unnamed: D50.2 (A), SW50.2
unnamed: D51.2 (A), SW51.2
unnamed: D52.2 (A), SW52.2
unnamed: D53.2 (A), SW53.2
unnamed: D54.2 (A), SW54.2
unnamed: D55.2 (A), SW55.2
unnamed: D56.2 (A), SW56.2
unnamed: D57.2 (A), SW57.2
unnamed: D58.2 (A), SW58.2
unnamed: D59.2 (A), SW59.2
unnamed: D60.2 (A), SW60.2
unnamed: D61.2 (A), SW61.2
unnamed: D62.2 (A), SW62.2
unnamed: D63.2 (A), SW63.2
unnamed: D64.2 (A), SW64.2
unnamed: D65.2 (A), SW65.2
unnamed: D66.2 (A), SW66.2
unnamed: RGB_LED1.2 (DOUT), RGB_LED6.4 (DIN)
unnamed: RGB_LED2.4 (DIN), RGB_LED35.2 (DOUT)
unnamed: RGB_LED2.2 (DOUT), RGB_LED8.4 (DIN)
unnamed: RGB_LED3.4 (DIN), RGB_LED36.2 (DOUT)
unnamed: RGB_LED3.2 (DOUT), RGB_LED9.4 (DIN)
unnamed: RGB_LED4.2 (DOUT), RGB_LED10.4 (DIN)
unnamed: RGB_LED10.2 (DOUT), RGB_LED24.4 (DIN)
unnamed: RGB_LED5.2 (DOUT), RGB_LED11.4 (DIN)
unnamed: RGB_LED11.2 (DOUT), RGB_LED25.4 (DIN)
unnamed: RGB_LED12.4 (DIN), RGB_LED39.2 (DOUT)
unnamed: RGB_LED12.2 (DOUT), RGB_LED26.4 (DIN)
unnamed: RGB_LED13.4 (DIN), RGB_LED40.2 (DOUT)
unnamed: RGB_LED13.2 (DOUT), RGB_LED27.4 (DIN)
unnamed: RGB_LED14.4 (DIN), RGB_LED41.2 (DOUT)
unnamed: RGB_LED14.2 (DOUT), RGB_LED28.4 (DIN)
unnamed: RGB_LED15.4 (DIN), RGB_LED42.2 (DOUT)
unnamed: RGB_LED15.2 (DOUT), RGB_LED29.4 (DIN)
unnamed: RGB_LED16.4 (DIN), RGB_LED43.2 (DOUT)
unnamed: RGB_LED16.2 (DOUT), RGB_LED30.4 (DIN)
unnamed: RGB_LED17.4 (DIN), RGB_LED44.2 (DOUT)
unnamed: RGB_LED17.2 (DOUT), RGB_LED31.4 (DIN)
unnamed: RGB_LED18.4 (DIN), RGB_LED45.2 (DOUT)
unnamed: RGB_LED18.2 (DOUT), RGB_LED32.4 (DIN)
unnamed: RGB_LED19.4 (DIN), RGB_LED65.2 (DOUT)
unnamed: RGB_LED19.2 (DOUT), RGB_LED33.4 (DIN)
unnamed: RGB_LED6.2 (DOUT), RGB_LED20.4 (DIN)
unnamed: RGB_LED20.2 (DOUT), RGB_LED34.4 (DIN)
unnamed: RGB_LED7.2 (DOUT), RGB_LED21.4 (DIN)
unnamed: RGB_LED21.2 (DOUT), RGB_LED60.4 (DIN)
unnamed: RGB_LED8.2 (DOUT), RGB_LED22.4 (DIN)
unnamed: RGB_LED22.2 (DOUT), RGB_LED48.4 (DIN)
unnamed: RGB_LED9.2 (DOUT), RGB_LED23.4 (DIN)
unnamed: RGB_LED23.2 (DOUT), RGB_LED49.4 (DIN)
unnamed: RGB_LED24.2 (DOUT), RGB_LED50.4 (DIN)
unnamed: RGB_LED25.2 (DOUT), RGB_LED51.4 (DIN)
unnamed: RGB_LED26.2 (DOUT), RGB_LED52.4 (DIN)
unnamed: RGB_LED27.2 (DOUT), RGB_LED53.4 (DIN)
unnamed: RGB_LED28.2 (DOUT), RGB_LED54.4 (DIN)
unnamed: RGB_LED29.2 (DOUT), RGB_LED55.4 (DIN)
unnamed: RGB_LED30.2 (DOUT), RGB_LED56.4 (DIN)
unnamed: RGB_LED31.2 (DOUT), RGB_LED57.4 (DIN)
unnamed: RGB_LED32.2 (DOUT), RGB_LED65.4 (DIN)
unnamed: RGB_LED33.2 (DOUT), RGB_LED46.4 (DIN)
unnamed: RGB_LED34.2 (DOUT), RGB_LED47.4 (DIN)
unnamed: RGB_LED35.4 (DIN), RGB_LED60.2 (DOUT)
unnamed: RGB_LED36.4 (DIN), RGB_LED61.2 (DOUT)
unnamed: RGB_LED37.4 (DIN), RGB_LED49.2 (DOUT)
unnamed: RGB_LED4.4 (DIN), RGB_LED37.2 (DOUT)
unnamed: RGB_LED38.4 (DIN), RGB_LED50.2 (DOUT)
unnamed: RGB_LED5.4 (DIN), RGB_LED38.2 (DOUT)
unnamed: RGB_LED39.4 (DIN), RGB_LED51.2 (DOUT)
unnamed: RGB_LED40.4 (DIN), RGB_LED62.2 (DOUT)
unnamed: RGB_LED41.4 (DIN), RGB_LED53.2 (DOUT)
unnamed: RGB_LED42.4 (DIN), RGB_LED54.2 (DOUT)
unnamed: RGB_LED43.4 (DIN), RGB_LED55.2 (DOUT)
unnamed: RGB_LED44.4 (DIN), RGB_LED63.2 (DOUT)
unnamed: RGB_LED45.4 (DIN), RGB_LED64.2 (DOUT)
unnamed: RGB_LED46.2 (DOUT), RGB_LED58.4 (DIN)
unnamed: RGB_LED47.2 (DOUT), RGB_LED59.4 (DIN)
unnamed: RGB_LED48.2 (DOUT), RGB_LED61.4 (DIN)
unnamed: RGB_LED52.2 (DOUT), RGB_LED62.4 (DIN)
unnamed: RGB_LED56.2 (DOUT), RGB_LED63.4 (DIN)
unnamed: RGB_LED57.2 (DOUT), RGB_LED64.4 (DIN)
unnamed: RGB_LED58.2 (DOUT), RGB_LED66.4 (DIN)
unnamed: RGB_LED7.4 (DIN), RGB_LED59.2 (DOUT)
RGB_Out: R1.1, U2., U2.1Y

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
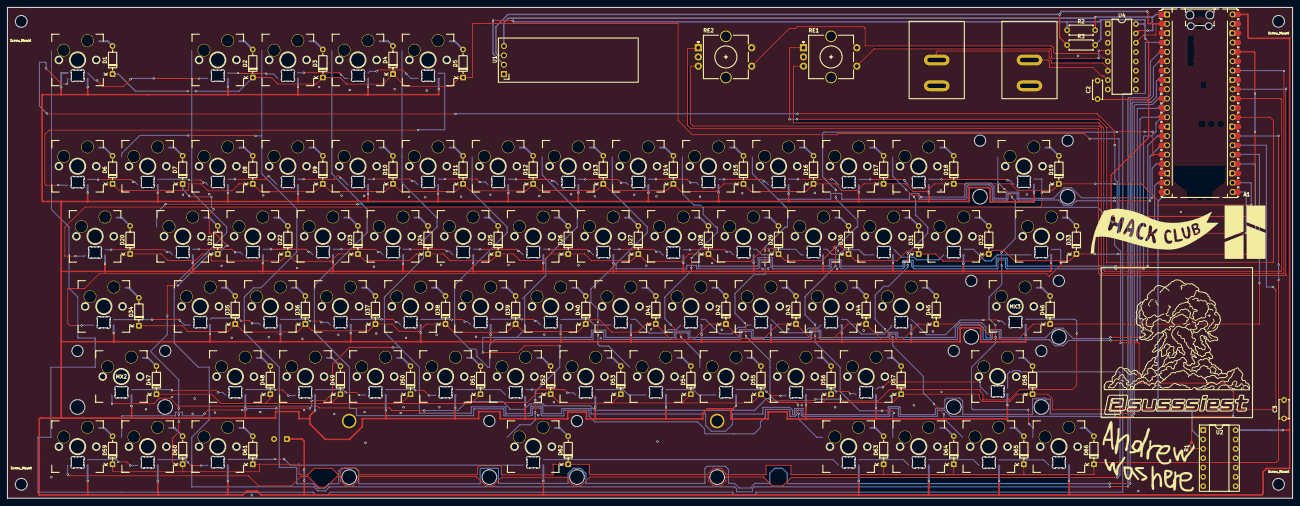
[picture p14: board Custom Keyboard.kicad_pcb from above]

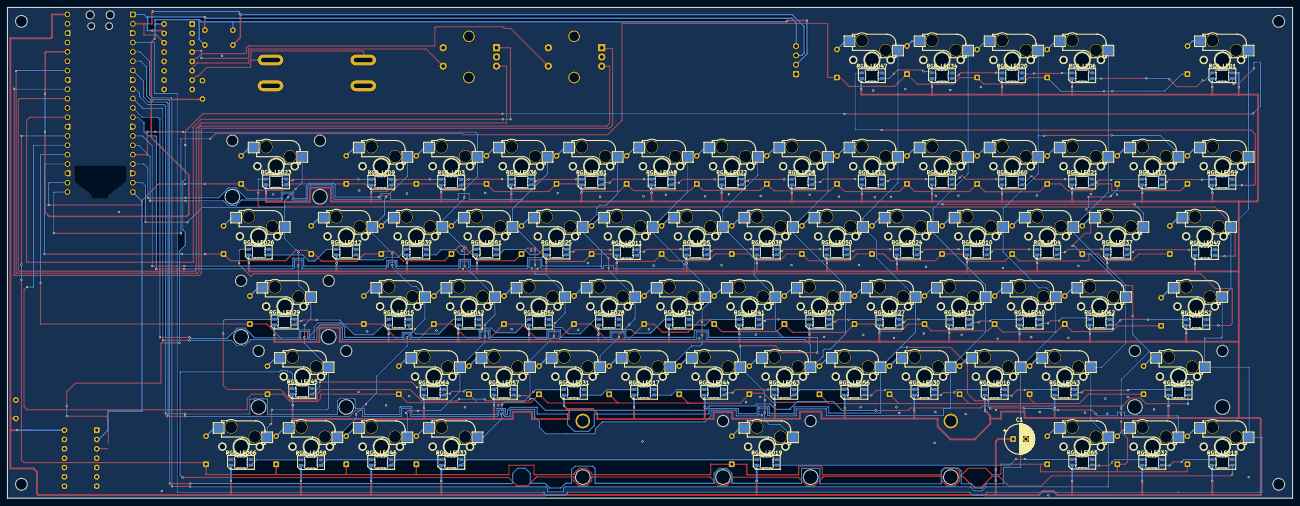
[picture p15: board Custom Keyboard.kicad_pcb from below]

Board: 2 copper layers, 349.3 x 133.3 mm, 222 parts (67 on the bottom side), 165 nets.

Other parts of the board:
MX5#2: MX_stab; STAB_MX_2u
SW1: SW_Push; MX_Hotswap
Screw_Mount: MountingHole_3.2mm_M3
Screw_Mount#2, Screw_Mount#3, Screw_Mount#4: MountingHole_3.2mm_M3
TS2#2: SW_SPST; KCD1_THT

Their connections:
/C0: SW1.1; also elsewhere on the board
GND: TS2#2.1 (A); also elsewhere on the board
unnamed 38: SW1.2; also elsewhere on the board

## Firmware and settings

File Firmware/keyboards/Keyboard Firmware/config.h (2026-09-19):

// Copyright 2026 Susssiest
// SPDX-License-Identifier: GPL-2.0-or-later
#pragma once

/* ---- I2C (OLED + PCF8574A expander share one bus) ----
 * GP0/GP1 are the RP2040's I2C0 pins. Note the deliberately confusing
 * QMK quirk: the pin defines keep the "I2C1_" prefix even when you
 * select the I2C0 peripheral. This is correct, not a typo. */
#define I2C_DRIVER   I2CD0
#define I2C1_SDA_PIN GP0
#define I2C1_SCL_PIN GP1
#define F_SCL        400000

/* ---- OLED: ER-OLEDM0.91, SSD1306, 128x32 ---- */
#define OLED_DISPLAY_128X32
#define OLED_TIMEOUT    0      // the right rocker owns the screen, not a timer
#define OLED_BRIGHTNESS 140

/* ---- RGB matrix ----
 * 66 WS2812s fed from Pico VBUS through its polyfuse on a 500 mA port.
 * Full white would ask for ~3.9 A, so brightness is hard-capped here and
 * in keyboard.json. Do not raise this without external 5 V power. */
#define RGB_MATRIX_MAXIMUM_BRIGHTNESS 110
#define RGB_MATRIX_SLEEP
#define RGB_MATRIX_KEYPRESSES

/* Default animation and colour live in keyboard.json (rgb_matrix.default):
 * cycle_left_right, full saturation, val 0. Val starts at 0 so the board
 * boots dark and fades up in keymap.c -- see the ramp section there. */

/* Diodes are 1N4148 with cathodes on the rows: COL2ROW. */
#define DEBOUNCE 5

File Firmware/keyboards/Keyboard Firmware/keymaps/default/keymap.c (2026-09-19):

// Copyright 2026 Susssiest
// SPDX-License-Identifier: GPL-2.0-or-later
//
// hackpad66 -- 66-key ANSI 60% + F-row, Raspberry Pi Pico
//   matrix   : 13 cols x 6 rows, COL2ROW (1N4148 cathodes on rows)
//   RGB      : 66 WS2812 on GP15 via SN74AHCT125N buffer
//   OLED     : SSD1306 128x32 on I2C0
//   expander : PCF8574A @ 0x38 -- 2 encoder buttons + 2 latching rockers
//
// ---------------------------------------------------------------------------
// !! READ THIS BEFORE DEBUGGING A "WRONG KEY" !!
//
// Three switches are wired into matrix row 5 even though they sit physically
// in other rows. This was done to free a GPIO pin, and nothing in the
// electrical design hints at it:
//
//     SW7   "1"        physically number row  -> matrix (row 5, col 2)
//     SW21  "Q"        physically QWERTY row  -> matrix (row 5, col 3)
//     SW60  Left Opt   physically bottom row  -> matrix (row 5, col 4)
//
// The LAYOUT_66 macro below is in *physical* reading order, so you should
// never need to think about this -- but if one of those three keys ever
// misbehaves, this is why.
// ---------------------------------------------------------------------------

#include QMK_KEYBOARD_H
#include "i2c_master.h"
#include <string.h>
#include <stdio.h>

enum layers { _BASE = 0, _FN };

enum custom_keycodes {
    WS_NEXT = QK_USER,  // encoder 2 clockwise  -> Cmd-Tab forward
    WS_PREV,            // encoder 2 counter-cw -> Cmd-Tab backward
};

// ===========================================================================
//  Keymap
// ===========================================================================

const uint16_t PROGMEM keymaps[][MATRIX_ROWS][MATRIX_COLS] = {

    [_BASE] = LAYOUT_66(
        KC_ESC,  KC_F1,   KC_F2,   KC_F3,   KC_F4,
        KC_GRV,  KC_1,    KC_2,    KC_3,    KC_4,    KC_5,    KC_6,    KC_7,    KC_8,    KC_9,    KC_0,    KC_MINS, KC_EQL,  KC_BSPC,
        KC_TAB,  KC_Q,    KC_W,    KC_E,    KC_R,    KC_T,    KC_Y,    KC_U,    KC_I,    KC_O,    KC_P,    KC_LBRC, KC_RBRC, KC_BSLS,
        KC_CAPS, KC_A,    KC_S,    KC_D,    KC_F,    KC_G,    KC_H,    KC_J,    KC_K,    KC_L,    KC_SCLN, KC_QUOT, KC_ENT,
        KC_LSFT, KC_Z,    KC_X,    KC_C,    KC_V,    KC_B,    KC_N,    KC_M,    KC_COMM, KC_DOT,  KC_SLSH, KC_RSFT,
        KC_LCTL, KC_LALT, KC_LGUI,          KC_SPC,                    KC_RGUI, KC_RALT, MO(_FN), KC_RCTL
    ),

    // Fn layer. QK_BOOT lives on Fn+Esc -- the Pico's RUN pin is not broken
    // out to a button, so this is your only convenient way to reflash.
    [_FN] = LAYOUT_66(
        QK_BOOT, RM_TOGG, RM_NEXT, RM_VALD, RM_VALU,
        _______, KC_F1,   KC_F2,   KC_F3,   KC_F4,   KC_F5,   KC_F6,   KC_F7,   KC_F8,   KC_F9,   KC_F10,  KC_F11,  KC_F12,  KC_DEL,
        _______, _______, _______, _______, _______, _______, _______, _______, _______, _______, _______, _______, _______, _______,
        _______, _______, _______, _______, _______, _______, KC_LEFT, KC_DOWN, KC_UP,   KC_RGHT, _______, _______, _______,
        _______, _______, _______, _______, _______, _______, _______, _______, _______, _______, _______, _______,
        _______, _______, _______,          _______,                   _______, _______, _______, _______
    ),
};

#if defined(ENCODER_MAP_ENABLE)
// encoder_update_user() is end-of-life in current QMK, so the encoders are
// declared here and the interesting behaviour hangs off custom keycodes that
// process_record_user() intercepts.
const uint16_t PROGMEM encoder_map[][NUM_ENCODERS][NUM_DIRECTIONS] = {
    [_BASE] = { ENCODER_CCW_CW(KC_VOLD, KC_VOLU),   ENCODER_CCW_CW(WS_PREV, WS_NEXT) },
    [_FN]   = { ENCODER_CCW_CW(RM_VALD, RM_VALU),   ENCODER_CCW_CW(RM_PREV, RM_NEXT) },
};
#endif

// ===========================================================================
//  Encoder 2: the Cmd-Tab app switcher
// ===========================================================================
//
// Physical Cmd-Tab is "hold Cmd, tap Tab to advance, release Cmd to commit".
// An encoder cannot be held in a turned position -- it only emits pulses while
// actually rotating -- so "release Cmd" is driven by an inactivity timer
// instead: stop turning for CMDTAB_COMMIT_MS and the switcher commits.

#define CMDTAB_COMMIT_MS 1000  // how long after you stop turning before it commits
#define CMDTAB_FAST_MS     70  // detents closer together than this count as "spinning"
#define CMDTAB_FAST_STEP    2  // Tab taps per detent while spinning

static bool     cmdtab_held  = false;
static uint16_t cmdtab_idle  = 0;  // time of the last detent
static uint16_t cmdtab_last  = 0;  // for acceleration measurement

// Drop Cmd immediately and let macOS bring the highlighted app forward.
static void cmdtab_commit(void) {
    if (cmdtab_held) {
        unregister_code(KC_LGUI);
        cmdtab_held = false;
    }
}

static void cmdtab_step(bool forward) {
    if (!cmdtab_held) {
        register_code(KC_LGUI);
        cmdtab_held = true;
        // macOS needs a moment to put the switcher on screen before it will
        // act on Tab presses. Without this the first detent is often eaten.
        wait_ms(30);
    }

    uint8_t steps = 1;
    if (cmdtab_last && TIMER_DIFF_16(timer_read(), cmdtab_last) < CMDTAB_FAST_MS) {
        steps = CMDTAB_FAST_STEP;
    }

    for (uint8_t i = 0; i < steps; i++) {
        if (forward) {
            tap_code(KC_TAB);
        } else {
            // Cmd stays down; Shift is added only for this tap.
            register_code(KC_LSFT);
            tap_code(KC_TAB);
            unregister_code(KC_LSFT);
        }
    }

    cmdtab_last = timer_read();
    cmdtab_idle = cmdtab_last;
}

// ===========================================================================
//  PCF8574A expander -- 2 encoder buttons, 2 latching rockers
// ===========================================================================
//
// The PCF8574 has no direction register. You put a pin into "input" by
// writing a 1 to it, which leaves only a weak ~100 uA pull-up holding it
// high. Every switch here shorts its pin to GND, so asserted == 0.

#define EXP_ADDR    (0x38 << 1)   // QMK wants the address in the upper 7 bits
#define EXP_TIMEOUT 20
#define EXP_POLL_MS 15

#define EXP_RE1_BTN (1 << 0)      // encoder 1 shaft  -> mute
#define EXP_RE2_BTN (1 << 1)      // encoder 2 shaft  -> Mission Control
#define EXP_ROCK_L  (1 << 2)      // left rocker      -> RGB on/off
#define EXP_ROCK_R  (1 << 3)      // right rocker     -> screen on/off

static uint8_t  exp_stable  = 0xFF;  // last debounced reading
static uint8_t  exp_pending = 0xFF;  // candidate awaiting confirmation
static uint16_t exp_timer   = 0;
static bool     exp_primed  = false;

static bool exp_read(uint8_t *out) {
    return i2c_receive(EXP_ADDR, out, 1, EXP_TIMEOUT) == I2C_STATUS_SUCCESS;
}
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

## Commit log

2026-08-08 Update README with project details and schematics
    Expanded project description with details on design and components used.
2026-08-10 Update README with PCB design and LED details
    Added details about PCB design process and LED orientation issues.
2026-08-12 Update README with case design details
    Added a section about the case design and included images.
2026-08-12 Add project writeup to README
    Added a project writeup detailing the PCB design experience and features of the keyboard project.
2026-08-29 Update Custom Keyboard BOM with stabilizers
    Added stabilizers to the BOM and ensured proper formatting.
    [Custom Keyboard BOM.csv]
2026-08-29 Enhance README with project journal details
    Expanded the README to include detailed project journal entries covering schematics, PCB orientation, routing, case design, and finishing touches.
2026-08-29 Replacing files
    [Custom Keyboard-B_Adhesive.gbr, Custom Keyboard-B_Courtyard.gbr, Custom Keyboard-B_Cu.gbr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]
2026-08-29 replacing bom
    [Custom Keyboard BOM.csv, Keyboard BOM.csv]
2026-08-29 moving files around
    [Case_1.stl, Case_2.stl, Custom Keyboard.kicad_pcb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]
2026-08-29 Update BOM section header in README.md
2026-08-29 Revise README with new section headers and BOM
    Updated section headers and added a BOM section.
2026-09-16 Converting step to stl
    [Case_1.step, Case_1.stl, Case_2.step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]
2026-09-17 Replacing old fabrication files
    [Custom Keyboard-B_Adhesive.gbr, Custom Keyboard-B_Courtyard.gbr, Custom Keyboard-B_Cu.gbr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]
2026-09-17 Replacing old fab files
    [Custom Keyboard-B_Adhesive.gbr, Custom Keyboard-B_Courtyard.gbr, Custom Keyboard-B_Cu.gbr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]
2026-09-17 final fab replacment
    [Custom Keyboard-B_Adhesive.gbr, Custom Keyboard-B_Courtyard.gbr, Custom Keyboard-B_Cu.gbr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]
2026-09-18 Rearranging files
    [.kicad_sch, .kicad_sch.kicad_sch, Custom Keyboard BOM.csv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]
2026-09-18 reolacing files
    [Custom Keyboard 2.kicad_sch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]
2026-09-18 more replacing grbs lol
    [Custom Keyboard-B_Adhesive.gbr, Custom Keyboard-B_Courtyard.gbr, Custom Keyboard-B_Cu.gbr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]
2026-09-18 swap pcb render
2026-09-19 replacing grbs
    [Custom Keyboard-B_Adhesive.gbr, Custom Keyboard-B_Courtyard.gbr, Custom Keyboard-B_Cu.gbr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]
2026-09-19 replacing fabs
    [Custom Keyboard-B_Adhesive.gbr, Custom Keyboard-B_Courtyard.gbr, Custom Keyboard-B_Cu.gbr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]
2026-09-19 Revise JOURNAL.md with project updates
    Updated project journal with detailed sections on schematics, PCB orientation, routing, case design, silkscreen addition, data shifter integration, and GPIO extender replacement. Corrected level shifter footprint and added resistors.
2026-09-19 replacing fabs agfain lol
    [Custom Keyboard-B_Adhesive.gbr, Custom Keyboard-B_Courtyard.gbr, Custom Keyboard-B_Cu.gbr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]
2026-09-19 Add QMK firmware for Keyboard (66)
    66-key ANSI 60% + F-row on a Raspberry Pi Pico.
    - 13x13 COL2ROW matrix, cols GP2-GP14, rows GP16-GP21
    - 66 WS2812 per-key RGB on GP15 via SN74AHCT125N, brightness capped at 110
    - SSD1306 128x32 OLED on I2C0 (GP0/GP1), shows currently held key combo
    - PCF8574A expander at 0x38 for 2 encoder buttons and 2 latching rockers
    - Encoder 1 volume/mute; encoder 2 drives the macOS Cmd-Tab switcher with
    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
2026-09-19 RGB: default to a moving rainbow across the keys
    Verified every pin against the full schematic: columns C0-C12 on GP2-GP14,
    rows R0-R5 on GP16-GP21, RGB data on GP15, I2C on GP0/GP1, encoders on
    GP22/GP26 and GP27/GP28, PCF8574AP at 0x38 with A0-A2 grounded. All matrix
    pins are on the Pico; the expander carries only the two encoder buttons and
    two rocker switches.
    Default animation was solid white, which was wrong -- it is now
    cycle_left_right at full saturation. Brightness still starts at 0 and fades
    up after USB enumeration; the animation drives hue itself.
    [config.h, keymap.c]
2026-09-20 plotted schematic
    [Custom Keyboard.kicad_sch]
2026-09-20 Add BOM section to README with image
    Added a BOM section with an image to the README.
2026-09-20 Update journal with schematic issue details
    Added note about schematic reverting and redoing capacitors.
2026-09-20 replacing gbrs
    [Custom Keyboard-B_Adhesive.gbr, Custom Keyboard-B_Courtyard.gbr, Custom Keyboard-B_Cu.gbr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]
2026-09-21 replacing kicad
2026-09-21 Correct KCD1 footprint and update image
    Updated the KCD1 footprint in the PCB design after correcting the pin hole sizes. Added a new image to reflect the changes made.
2026-09-21 Document keyboard project progress in README
    Added detailed journal entries documenting the keyboard project progress, including schematics, PCB design, routing, case design, and finalization steps.
2026-09-21 updating kicad
    [Custom Keyboard.kicad_pcb]
2026-09-22 Update README with component details and images
    Added details about LEDs, rotary encoders, SPST switches, and OLED display functionality. Included images for visual reference.
2026-09-22 Modify LED section and update image in README
    Updated image dimensions in README and clarified LED setup details.
2026-09-23 syncing updated files
    [Case_1.step, Case_2.step, Case_Half_1.step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]
2026-09-23 replacing cad
    [Case_Half_1.step, Case_Half_1.stl, Case_Half_2.step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]
2026-09-23 adding renders
    [Keyboard_SLICER.3mf]
2026-09-23 update fabs and pcb renders
    [Custom Keyboard-B_Adhesive.gbr, Custom Keyboard-B_Courtyard.gbr, Custom Keyboard-B_Cu.gbr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]
2026-09-23 BOM update
    [Keyboard BOM.csv]
2026-09-23 ANOTHER BOM UPDATE
    [Keyboard BOM.csv]
2026-09-23 updatign fabs
    [Custom Keyboard-B_Adhesive.gbr, Custom Keyboard-B_Courtyard.gbr, Custom Keyboard-B_Cu.gbr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]
2026-09-23 updating BOM
    [Custom Keyboard BOM.csv, Keyboard BOM.csv]
2026-09-29 updating grbs and blend
    [Custom Keyboard-B_Adhesive.gbr, Custom Keyboard-B_Courtyard.gbr, Custom Keyboard-B_Cu.gbr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]
2026-10-03 Update JOURNAL.md with animation redesign details
    Redid the animation for PCB components with new key placements and added a rotary encoder knob render.
